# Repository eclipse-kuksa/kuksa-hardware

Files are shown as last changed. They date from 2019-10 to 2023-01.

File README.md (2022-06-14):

# Eclipse KUKSA CANOPi  Hardware 

This repository contains information and manufacturing files for the CANOPi automotive prototyping plattform.

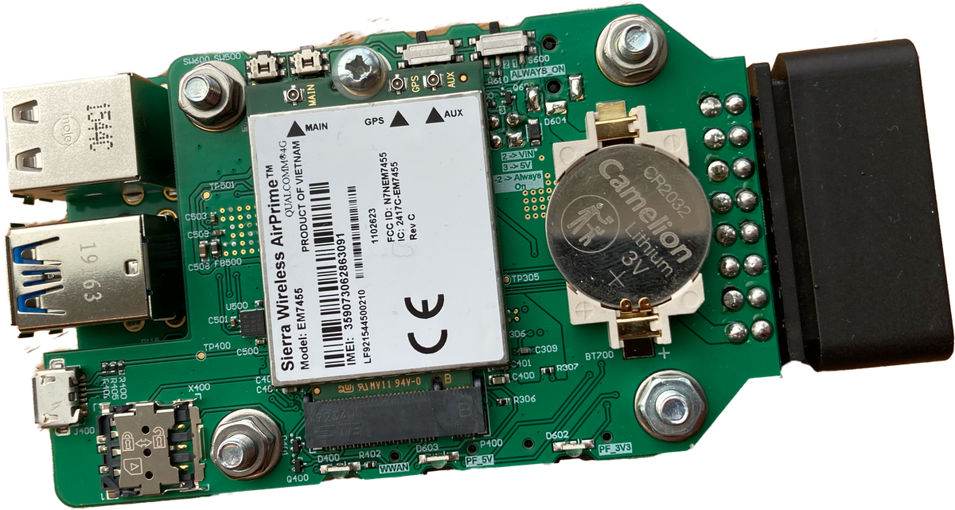
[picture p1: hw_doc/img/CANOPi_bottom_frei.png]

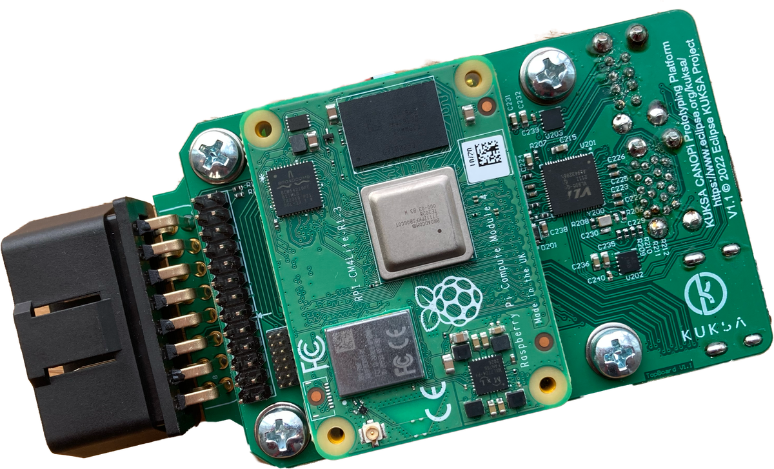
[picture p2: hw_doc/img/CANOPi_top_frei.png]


The Eclipse KUKSA CANOPi is a baseboard for the [Raspberry Compute Module 4 (CM4)](https://www.raspberrypi.com/products/compute-module-4).

With the CANOPi you have all the ingredients for hacking vehicles and prototyping Software Defined Vehicle functions and applications.

 * Compatible with the Raspberry Pi ecosystem thanks to the CM4
 * Up to 8GB of RAM and up to 32GB eMMC or any size micro SD card storage
 * integrated SIM card slot and M2 slot to add cellular connectivity
 * Can be powered via a vehicle's [OBD Port](https://en.wikipedia.org/wiki/On-board_diagnostics#OBD-II) 
 * [STN2120 OBD-II](https://www.obdsol.com/solutions/chips/stn2120/) to access vehicle data on OBD (only CAN supported by hardware)
 * Two [MCP251xFD](https://www.microchip.com/en-us/product/MCP2518FD) based [CAN-FD](https://en.wikipedia.org/wiki/CAN_FD) interfaces allowing interfacing two vehicle classic CAN or CAN FD busses directly.
 * [PCF85036A Realtime clock](https://www.nxp.com/products/peripherals-and-logic/signal-chain/real-time-clocks/rtcs-with-ic-bus/tiny-real-time-clock-calendar-with-alarm-function-and-ic-bus:PCF850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)

## What you can find here
 * Find schematics board renders and BOM lists in [./hw_doc/](./hw_doc/)
 * You can find GERBER files needed to manufacture the PCB in [./manufacturing](./manufacturing) 
 * [Altium Designer](https://www.altium.com/altium-designer) EDA project file nn case you want to modify the schematics can be found in [./EDA](./EDA). 

## How to setup

If you set up a fresh CM4 that has never been used before in CANOPi you need to update the EEPROM first

 * [Updating CM4 EEPROM for CANOPi](./sw_doc/update_eeprom.md)

 In order to make full use of all hardware components, you need to configure your Raspberry OS

  * [Enabling Hardware support in your OS](./sw_doc/configure_raspberryos.md)

If you use a compute module with integrated flash (eMMC), read

 * [How to flash eMMC compute modules](./sw_doc/flash-emmc.md)

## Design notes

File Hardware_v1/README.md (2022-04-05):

# Eclipse Kuksa Hardware V1

:bangbang: | This folder contains documentation and manufacturing data for version 1 of the KUKSA hardware. For documentation regarding the current version [see here](../README.md)
:---: | :---

Eclipse Kuksa Figure
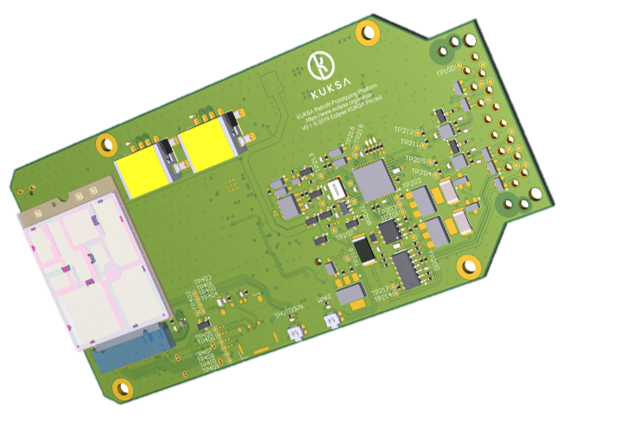
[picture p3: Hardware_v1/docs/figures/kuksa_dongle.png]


This repository contains information about the the Eclipse Kuksa project and available hardware.
It includes hardware schematics and manufacturing files, housing details for 3D printers, as
well as a setup guide. Please use the links below to one of the manuals.

## Eclipse Kuksa Retrofit Dongle

While [Eclipse Kuksa](https://www.eclipse.org/kuksa/) cares about to interconnect
vehicles with external services, typically vehicles already on the road do not
provide any mechanisms to install software afterwards. The Eclipse Kuksa prototyping
platform describes a retrofit solution for already existing vehicles. It can be
directly connected to the in-vehicle OBD II interface. The platform combines a
Raspberry Pi Compute Module, several options to communicate information
(e.g., via cellular or WiFi connectivity) and access to OBD. The most important
information can be accessed in the links below.

## Operational Matters

* [Hardware Schematics](./hardware/Readme.md)
* [3D Housing](./housing/README.md)
* [Setup Guide](./docs/README.md)

## The Project
* [Eclipse Kuksa](https://www.eclipse.org/kuksa/)
* [Licensing](./LICENSE)

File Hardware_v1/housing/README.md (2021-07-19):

# KUKSA.hardware housing

This contains 3d-printable STL files for a housing. 

[housing-top.stl](./housing-top.stl) and [housing-bottom.stl](./housing-bottom.stl) give you the main case (with some handy cutouts from HDMI and the OTG USB port for debugging), while [antenna-bracket-basic.stl](./antenna-bracket-basic.stl) and [antenna-bracket-lock.stl](./antenna-bracket-lock.stl) give support for an LTE antenna and active GPS antenna.

To see how this looks assembled, check the [KUKSA_PiOBD_V0.3.pdf](./KUKSA_PiOBD_V0.3.pdf) file. Please note, the PDF contains a 3D model of the dongle itself inside the housing. This type of content is not supported by many PDF viewers. Therefore, we recommend using the original [Adobe Reader](https://get.adobe.com/reader/) to view it.

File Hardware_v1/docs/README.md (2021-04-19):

# Kuksa Dongle Setup Manual

This documentation provides information about setting up the Kuksa dongle.

## Table of Contents
1. [Hardware Pre-requisites](#hardware-pre-requisites)
2. [OS Installation](#installation-of-os)  
 2.1 [Raspbian OS](#raspbian-os)  
 2.2 [Ubuntu OS](#ubuntu-os)
3. [OBD STN2120 Configuration](#obd-stn2120-configuration)
4. [Configure WiFi Access Point](#configure-wireless-access-point-interface)  
 4.1 [Hostapd Configuration](#hostapd-configuration)  
 4.2 [Dnsmasq Configuration](#dnsmasq-configuration)  
 4.3 [Wireless Interface and Static IP](#wireless-interface-and-static-ip)
5. [Troubleshooting](#troubleshooting)

## Hardware Pre-requisites

##### Mandatory

The Kuksa Dongle is constructed to host and power a Raspberry Pi Compute Module 3 or 3+. Such compute module is required for the dongle and needs to be available.
Check official Raspberry Pi website for further information on the [Raspberry Pi Compute Module 3](https://www.raspberrypi.org/products/compute-module-3/).  
There are actually several versions you can order.
We can recommend to use a **Compute Module Lite** as it allows to mount a SD Card
with an associated operating system. This is much more convenient than flashing
the OS onto the board. In order to install any operating system, a SD card with
sufficient space (e.g., 32GB) is required.

* RaspberryPi Compute Module 3
* SD card (32 GB)

##### Optional

In order to be able to send and receive messages via the OBD interface, a OBD-II emulator like the [FreeMatics OBD-II Emulator Mk2](https://freematics.com/products/freematics-obd-emulator-mk2/) is recommended.

## Installation of OS

This guide provides information to install either the Raspbian OS (32bit system), as well as an Ubuntu Server (headless, 64bit system). If you plan to use the [Kuksa.val](https://github.com/eclipse/kuksa.val) Docker containers, we recommend to install the Ubuntu Server (64bit) system.

### Raspbian OS

Most convenient way to setup an operating system for Raspberry Pi is the Raspbian OS.
We tested the Dongle with [Raspbian LITE OS](https://www.raspberrypi.org/software/operating-systems/) in kernel version 5.10.
Download it from the Raspberry Pi website and install the image on a SD card (e.g., using the [Balena Etcher](https://www.balena.io/etcher/) tool).

When you boot the OS the first time, you need to disable the serial console (otherwise you will face a kernel panic). This is due to the fact, that the port is used by the OBD-II protocol decoder.
You have to mount */boot partition* of the SD card (e.g., Windows or Linux machine), and edit the **cmdline.txt** by deleting the **console=serial0,115200** command. Change it from

```sh
# before the changes
dwc_otg.lpm_enable=0 console=serial0,115200 console=tty1 root=PARTUUID=<PARTION_UUID_VALUE> rootfstype=ext4 elevator=deadline fsck.repair=yes rootwait quiet splash plymouth.ignore-serial-consoles
```
to

```sh
# after the changes
dwc_otg.lpm_enable=0 console=tty1 root=PARTUUID=<PARTION_UUID_VALUE> rootfstype=ext4 elevator=deadline fsck.repair=yes rootwait quiet splash plymouth.ignore-serial-consoles
```
After the changes you can plug the SD card into the dongle, power it up and log into it using the default user:password credentials of Raspian ("*pi:raspberry*").

### Ubuntu OS

The Kuksa Dongle uses a Raspberry Pi Compute Module 3 B+ (w/o internal storage).
This allows us to use a Raspberry Pi compliant operating system on a SD card.
We are using an ARM supported [Ubuntu Server](https://ubuntu.com/download/raspberry-pi/thank-you?version=20.04.2&architecture=server-arm64+raspi) (64bit system - ARM compliant - headless).

In this version of documentation, Ubuntu 20.10 is used -- Problems are faced when using Ubuntu 20.04 LTS.

Download it from the Ubuntu website and install the image on a SD card (e.g., using the [Balena Etcher](https://www.balena.io/etcher/) tool).

When you boot the OS the first time, you need to disable the serial console (otherwise you will face a kernel panic) as well as some labling of network interfaces.

You have to mount */boot partition* of the SD card (e.g., Windows or Linux machine), and edit the **cmdline.txt** by deleting the **console=serial0,115200** command. Change it from

```sh
# before the changes
dwc_otg.lpm_enable=0 console=serial0,115200 console=tty1 root=LABEL=writable rootfstype=ext4 elevator=deadline rootwait fixrtc quiet splash
```
to

```sh
# after the changes
dwc_otg.lpm_enable=0 console=tty1 root=LABEL=writable rootfstype=ext4 elevator=deadline rootwait fixrtc net.ifnames=0
```
After the changes you can plug the SD card into the dongle, power it up and log in with the default Ubuntu credentials (**ubuntu:ubuntu**). Ubuntu will ask you immediately to provide a new password of your choice.

#### Configure Network Interfaces in Ubuntu

In Ubuntu 20.10, **Netplan** is used to configure network interfaces. In order to configure wired and wireless network interfaces, you have to configure the **50-cloud-init.yaml** file, for example:

```sh
ubuntu@ubuntu:~$ sudo nano /etc/netplan/50-cloud-init.yaml
...
...
# This file is generated from information provided by the datasource.  Changes
# to it will not persist across an instance reboot.  To disable cloud-init's
# network configuration capabilities, write a file
# /etc/cloud/cloud.cfg.d/99-disable-network-config.cfg with the following:
# network: {config: disabled}
network:
    renderer: networkd
    ethernets:
        eth0:
            dhcp4: true
            optional: true
            #set-name: eth0
    version: 2
    wifis:
        wlan0:
            optional: true
            access-points:
                "<SSID>":
                    password: "<PASSWD>"
            dhcp4: true
```

Where **<SSID>** is the identification name of your Wifi network and **<PASSWD>** is the password to authenticate the node to your Wifi network. Once the network has been configured, you have to restart the network manager or reboot your system to get the changes effective.

## OBD STN2120 Configuration

The board is designed to use the [STN2120 Chip](https://www.obdsol.com/solutions/chips/stn2120/) for OBD-II connectivity to send and receive messages form a Controller Area Network (CAN). The chip is ELM327 compatible, but bigger, faster and meaner!. You have to configure the baud rate of the CAN transceiver to the serial console in order to receive messages correctly.

Once you have installed any Debian based operating system (e.g., Raspbian OS, or Ubuntu), you have to configure the ELM327 serial bus to read/write to CAN transceiver. On the Dongle, you have to establish a connection to the CAN transceiver (e.g., using the "screen" command line tool - use "sudo apt get install screen" if not installed). Via "dmesg" you can check for the CAN transceiver device (typically */dev/ttyAMA0*).
Once connected, you need to configure the ELM327 baud rate. You can check the entire [STN2120 Chip Manual](https://www.scantool.net/scantool/downloads/98/stn11xx21xx_frpm-c.pdf) for further configuration options.

```sh
# connect to the ELM327 serial bus using 'screen'
kuksa@pi:~$ sudo screen /dev/ttyAMA0 9600
> STSBR 2000000     # configure the baud rate to 2 MBit/s in RAM
> "OK"              # prompts OK
> <CTRL + K>        # exit screen or CTRL + ALT + DEL to reboot the Dongle
# connect again to persist the config changes
kuksa@pi:~$ sudo screen /dev/ttyAMA0 2000000
> STWBR             # persist baud rate in ROM -> there will be NO response
> <CTRL + K>        # exit screen or CTRL + ALT + DEL to reboot the Dongle
```

You are DONE. Your CAN transceiver is configured. In order to test your CAN communication, you can create a Python script to test the CAN communication (e.g., https://python-obd.readthedocs.io/en/latest/). Please check the python-obd manual to check the properties to set to connect to the serial bus and configure the new baud rate.

```python
# pip3 install obd
# python3 python-obdtest.py
import obd

connection = obd.OBD(portstr="/dev/ttyAMA0", baudrate=2000000) # create connection

cmd = obd.commands.SPEED # select an OBD command (sensor)

response = connection.query(cmd) # send the command, and parse the response

print(response.value) # returns unit-bearing values thanks to Pint
print(response.value.to("mph")) # user-friendly unit conversions
```

We suggest to use the FreeMatics OBD-II Emulator Mk2: https://freematics.com/products/freematics-obd-emulator-mk2/  to send CAN messages to the Kuksa Dongle which you should receive on the Python script.

## Configure Wireless Access Point Interface

In order to be able to access in-vehicle data in a real deployment of the Dongle, wireless connectivity is required.
The simplest way to achieve such functionality is to configure a wireless network interface to act as an access point using WiFi.

#### Why do you need a WiFi USB Dongles and which one?

As the Raspberry Pi Compute Module 3 does not provide a WiFi card onboard, you have to order a **mini** WiFi USB dongle (small form factor to fit into the Kuksa Dongle housing). Not all dongles work out of the box with Ubuntu due to missing support of the chip set in the Linux kernel. We tested a couple of Dongles (in 2020/2021) and had good experience with WiFi Dongles equipped with a **Ralink RT5370** chip (e.g., [EDUP Nano Adapter EP at Amazon](https://www.amazon.de/-/en/gp/product/B00BXWU7X4/ref=ppx_yo_dt_b_asin_title_o00_s00?ie=UTF8&psc=1)).

### Pre-requisites

To configure a access point on the Kuksa Dongle, we need three features: (i) tool to switch a Wifi PHY/MAC into access point mode - here using **hostapd**, (ii) a tool to act as a DHCP server and route traffic on this interface accordingly - here using **dnsmasq**, and (iii) configuring a wireless network interface in you network manager (e.g., using netplan or systemd-networkd). In this documentation we are using **systemd-networkd** which is more stable and simple to configure the network interface compared to netplan.

Install the tools via command line:

```sh
ubuntu@ubuntu:~$ sudo apt install hostapd dnsmasq
```

**Attention: When you have set up a wireless interface previously to operate as a client (cf. [Configure Network Interfaces in Ubuntu](#configure-network-interfaces-in-ubuntu)), you have to ensure that you are configuring the right interface to act as a WiFi access point. In case it should be the previously configured *wlan0* interface, you have to delete the lines configured */etc/netplan/50-cloud-init.yaml* file accordingly. If you want to configure an additional one, make sure you are configuring the right interface in the upcoming subsections.**

### Hostapd Configuration

Hostapd allows us to switch a WiFi card or WiFi USB dongle into the access point mode and to configure access point related information such as the SSID or the authentication password. After installing the tool, you have to provide a configuration for your access point. Write the following lines in the configuration file:

```sh
ubuntu@ubuntu:~$ sudo nano /etc/hostapd/hostapd.conf
interface=<INTERFACE>
driver=nl80211
ssid=<YOUR_SSID>
hw_mode=g
channel=7
wmm_enabled=0
macaddr_acl=0
auth_algs=1
ignore_broadcast_ssid=0
wpa=2
wpa_passphrase=<YOUR_PASSWORD>
wpa_key_mgmt=WPA-PSK
wpa_pairwise=TKIP
rsn_pairwise=CCMP
```
where *<INTERFACE>* is the network interface to switch into access point mode (e.g., wlan0), *<YOUR_SSID>* is the name of your wireless network (e.g., KuksaWifi), and *<YOUR_PASSWORD>* is the password used for authentication (make sure that your passphrase is at least 8 characters long).

You can check your configuration file using the following command:

```sh
ubuntu@ubuntu:~$ sudo hostapd -dd /etc/hostapd/hostapd.conf
```

After your configuration has been validated, we have to tell the hostapd systemd service which configuration file to be used (default is none - so change the line starting with *#DAEMON_CONF*) as well as enable the service at boot phase of the system.

```sh
ubuntu@ubuntu:~$ sudo nano /etc/default/hostapd
...
DAEMON_CONF="/etc/hostapd/hostapd.conf"
...
ubuntu@ubuntu:~$ sudo systemctl unmask hostapd
ubuntu@ubuntu:~$ sudo systemctl enable hostapd
ubuntu@ubuntu:~$ sudo systemctl start hostapd
```

When rebooting your system, you see your configured access network in the list of available WiFi networks (e.g., Laptop or SmartPhone). However, your device gets no IP address assigned so far - this is handled by *dnsmasq* (see below).

### Dnsmasq Configuration

Dnsmasq sets up a DHCP server and a router so devices connecting to the Kuksa Dongle can get an IP address assigned to it.

First, we recommend to make a backup of the default configuration file. After that, provide the inputs of your configuration and reload and enable the tool using systemctl.

By providing the inputs, you can un-comment the predefined entries in the file according to your setup. For a simple setup, the following lines are sufficient:

```sh
ubuntu@ubuntu:~$ sudo cp /etc/dnsmasq.conf /etc/dnsmasq.conf.BACKUP   # make a backup of the default conf
ubuntu@ubuntu:~$ sudo nano /etc/dnsmasq.conf
...
# to manage only WLAN0 interface - make sure the name of the interface is correct
interface=wlan0
# to assign addresses between 192.168.4.2 and 192.168.4.20 with netmask 255.255.255.0 and lease time 24 hours
dhcp-range=192.168.4.2,192.168.4.20,255.255.255.0,24h
...
```
On system startup, dnsmasq will not wait for the configured network interface (e.g., wlan0) to initialize and will fail with error "<INTERFACE> not found".

We need to configure the systemd service to launch after the network is ready. So you have to modify dnsmasq.service file by adding the right target under the *[Unit]* section.

```sh
ubuntu@ubuntu:~$ sudo nano /lib/systemd/system/dnsmasq.service
...
[Unit]
...
After=network-online.target
Wants=network-online.target
...
ubuntu@ubuntu:~$ sudo systemctl reload dnsmasq	# reload dnsmasq config
ubuntu@ubuntu:~$ sudo systemctl enable dnsmasq
```

### Wireless Interface and Static IP

Ubuntu uses by default cloud-init for the initial setup. But the configuration is not that simple/intuitive compared to systemd-networkd. So we are using this network management to configure the wireless network interface. A proper documentation of systemd-networkd can be found on the [Systemd-Networkd ArchLinux Website](https://wiki.archlinux.org/index.php/systemd-networkd).

In order to connect to a wireless network with **systemd-networkd**, a wireless adapter configured is required.

```sh
ubuntu@ubuntu:~$ sudo nano /etc/systemd/network/25-wireless.network
[Match]
Name=wlan0					      # the name of your interface you want to configure

[Network]
DHCP=no						        # 'no' as managed by dnsmasq
Address=192.168.4.1/24		# assign static IP address, link to dnsmasq

ubuntu@ubuntu:~$ sudo systemctl reload dnsmasq	# reload dnsmasq config
ubuntu@ubuntu:~$ sudo systemctl enable dnsmasq
```

After the creating the configuration, you have to reload the service and maybe also enable it to be executed after a reboot of the system.

You are done and should be able to connect another device to the Kuksa Dongle.

After rebooting your system, it could be possible that systemd-networkd is waiting for the network to be initialized, resulting in longer bootup time (message something like "a start job is waiting until the network is configured"). Different proposals to overcome the limitation are described on a [StackOverflow Thread](https://askubuntu.com/questions/972215/a-start-job-is-running-for-wait-for-network-to-be-configured-ubuntu-server-17-1).

## Troubleshooting

#### Failed to start OpenBSD Secure Shell Server
If you see, that sshd service can not be started correctly and ubuntu boots with error message: `Failed to start OpenBSD Secure Shell Server`, run the following command to generate missing key will fix the issue:

```sh
kuksa@pi:~$ sudo ssh-keygen -A
```

#### Enable Docker Daemon Autostart
If you want to use the docker images of the [Kuksa.val](https://github.com/eclipse/kuksa.val) and you do not want to start the containers every time, you can enable the Docker daemon to automatically start after installing docker on the Kuksa Dongle.

```sh
kuksa@pi:~$ sudo systemctl enable docker
```

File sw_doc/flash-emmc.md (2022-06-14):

# How to flash eMMC Compute Modules

Compute modules witout eMMC ("Lite" versions), boot from the SD card in the CANOPi socket.

Compute Modules with integrated eMMC flash _can not_ boot from an SD card (this is a CM4 hardware limitation), therefore you need to programm the integrated eMMC flash.

Basically the official documentation applies, which you can find [here](https://www.raspberrypi.com/documentation/computers/compute-module.html#flashing-the-compute-module-emmc), or in [Jeff Gerlings nice tutorial](https://www.jeffgeerling.com/blog/2020/how-flash-raspberry-pi-os-compute-module-4-emmc-usbboot
).

These tutorials assume you are using the official [Compute Module 4 IO Board](https://www.raspberrypi.com/products/compute-module-4-io-board/).
In a nutshell, you need to jumper the `nRPI_BOOT` / `disable eMMC boot` jumper connect your board to our computer where you ran a small piece of software, which basiclly turns you compute module into a (slow...) mass storage device exposing the eMMC flash.

So you are wondering, where to find the `nRPI_BOOT` signal to repeat this trickery directly on a CANOPi? 

Glad you asked:

You just need to put a 1.27mm Jumper over  the marked `nPIREBO` pins.

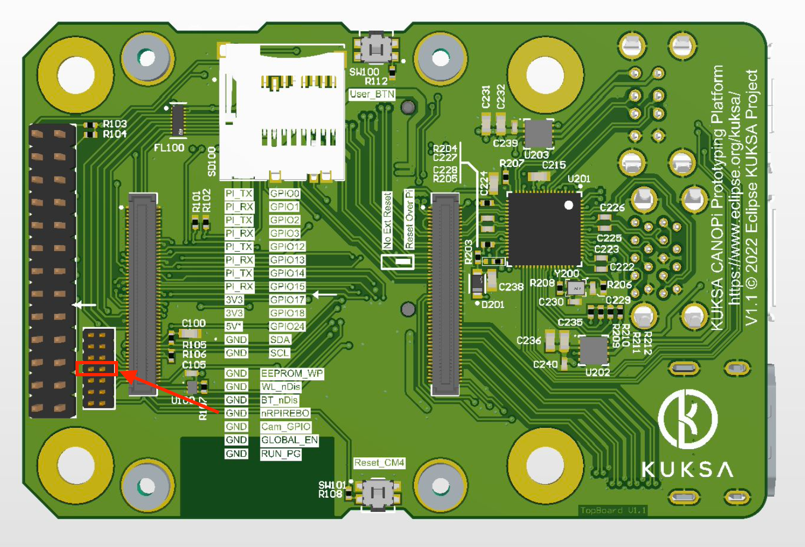
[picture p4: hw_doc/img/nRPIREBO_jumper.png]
nRPIREBO jumper


Do all the flashing as per the linked documentation above, possibly not forgetting to do the [neccessary Raspberry OS modifications](configure_raspberryos.md), remove the jumper and reboot.

Word of warning/friendly advice: Putting the jumper can be tricky and requires a steady hand. Using pincers is recommended. Obviously, only try to set/remove the jumper when the CANOPi is powered off.

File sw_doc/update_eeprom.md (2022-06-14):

# Updating CM4 EEPROM

The CANOPi contains a VIA VL805 4 Port USB controller, just like a "normal" Raspbbery Pi 4. This USB controller needs some firmware loaded up during system initialization, before Linux boots.

As a vanilla CM4 does not contain this USB controller, it will not do that. Therefore we need to update the EEPROM on board the CM4. Normally you only need to do this once for any new CM4, the changes will survice reinstalling or changing the operating system, as long as you do not update the EEPROM again.

The procedure desrcribed here involves a second Raspberry Pi (any will do) with a second SD-card.

## Step-by-step guide
[Prepare two SD-cards](https://www.raspberrypi.com/software/) with the most recent version of Raspberry Pi OS (at least the release of Oct 5th 2021).
One card is designated to be used for the CM4 in the CANOPi OBD dongle. Insert the _first_ card into a Raspberry Pi (any Pi will do - there, you have support for keyboard and mouse) and type

```
sudo nano /boot/config.txt
```

And add the following lines

```
enable_uart=1
dtoverlay=dwc2,dr_mode=host
````

Press Ctrl-X to leave the editor and choose to save your changes.

Then type

```
sudo nano /etc/default/rpi-eeprom-update
```

And change it to include these lines

```
FIRMWARE_RELEASE_STATUS="stable"
CM4_ENABLE_RPI_EEPROM_UPDATE=1
```

Again, press Ctrl-X and choose to save cahnges.

Now, insert this SD card into the CANOPi dongle. That is, the _first_ SD card now moved from the Pi to the CANOPi. Put the CANOPi to the side. We will need it later.

Proceed to the _second_ SD card and insert it into the Raspberry Pi and boot it.

Make sure the Pi has Internet access and type

```
sudo apt install git libusb-1.0-0-dev build-essential
```

Next install usbboot

```
git clone --depth=1 https://github.com/raspberrypi/usbboot
cd usbboot
make
```

Remove the pieeprom.original and replace with the one to flash. Navigate to and remove the original file by typing

```
cd ~/usbboot/recovery
rm -f pieeprom.original.bin
```

Download a recent stable eeprom from https://github.com/raspberrypi/rpi-eeprom/raw/master/firmware/stable/,
for example

```
curl -L -o pieeprom.original.bin https://github.com/raspberrypi/rpi-eeprom/raw/master/firmware/stable/pieeprom-2022-04-26.bin
```

Edit the **boot.conf** file to support the VL805 USB controller and configure proper poweroff behavior for CANOPi. Therefore, type

```
sudo nano ~/usbboot/recovery/boot.conf
```

And modify it to include the following lines

```
WAKE_ON_GPIO=0
POWER_OFF_ON_HALT=1

VL805=1
```

Press Ctrl-X and save.

Now update pieeprom.bin with the configuration in `boot.conf` by typing (still in `~/usbboot/recovery/`)

```
sudo ./update-pieeprom.sh
```

Now  prepare to flash the target by typing

```
cd ~/usbboot
sudo ./rpiboot -d recovery
```

Live the Pi. Now turn you attention back to the CANOPi.
Fit a jumper on `nRPIREBO` and `GND`. You can find the pin header on the top board. see the following picture for reference

nRPIREBO jumper

Fit a CM4. If you have followed this fine manual, the _first_ SD card is still inserted.

Now, connect one USB port from the Raspberry Pi to the microUSB port of the CANOPi dongle. Power on the CANOPi dongle and the flash process should initiate.  A regular blinking pattern of the green LED or, in case a screen is connected, an entirely green screen indicates a finished and successful flash procedure.

Now, power off CANOPi dongle, remove the jumper and power the board back on. The CANOPi dongle should boot normally and, once the CM4 is started, USB devices should be fully supported by the dongle.

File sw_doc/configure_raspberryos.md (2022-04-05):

# Enabling Hardware support in your OS

To be able to make use of all hardware on CANOPi you need to configure your Linux distribution accordingly.

This guide assumes you are using a current (as of 2022) Raspberry Pi OS version based on Debian Bullseye.

The instructions should work on other distributions that also follow the Raspberry OS boot procedure providing a similarly recent kernel.

Before booting the first time the OS on the device, you have to modify the `config.txt` file on the boot partition to extend the device tree. The device tree is the structure that tells the Linux kernel which hardware is available. As the boot partition is a FAT partition you can make these modifications easily even on Windows or OS X after [flashing the operating system](https://www.raspberrypi.com/software/), before booting the first time

## General settings
Make sure you have the following entries in you `config.txt`

```
enable_uart=1
dtoverlay=dwc2,dr_mode=host
```

also edit `cmdline.txt` and **remove** the entry `console=serial0,115200`

## CAN FD controllers
CANOPi has two CAN FD controllers connected via SPI. To enable than uncomment/add the following lines in `config.txt`

```
dtparam=spi=on
dtoverlay=mcp251xfd,spi0-0,interrupt=27,oscillator=20000000
dtoverlay=mcp251xfd,spi0-1,interrupt=22,oscillator=20000000
```

After reboot check, if the `can0` and `can1` interfaces are available, i.e. using

```
ifconfig -a
````

or

```
dmesg | grep spi
```

To learn how to configure the interfaces check [here](https://python-can.readthedocs.io/en/master/interfaces/socketcan.html) or [here](https://www.kernel.org/doc/html/latest/networking/can.html) for more in-depth information

## STN2120 OBD controller

Fit jumpers between GPIO15 and PI_RX and GPIO14 and PI_TX.

You can find the headers on the top board, see the following picture for reference

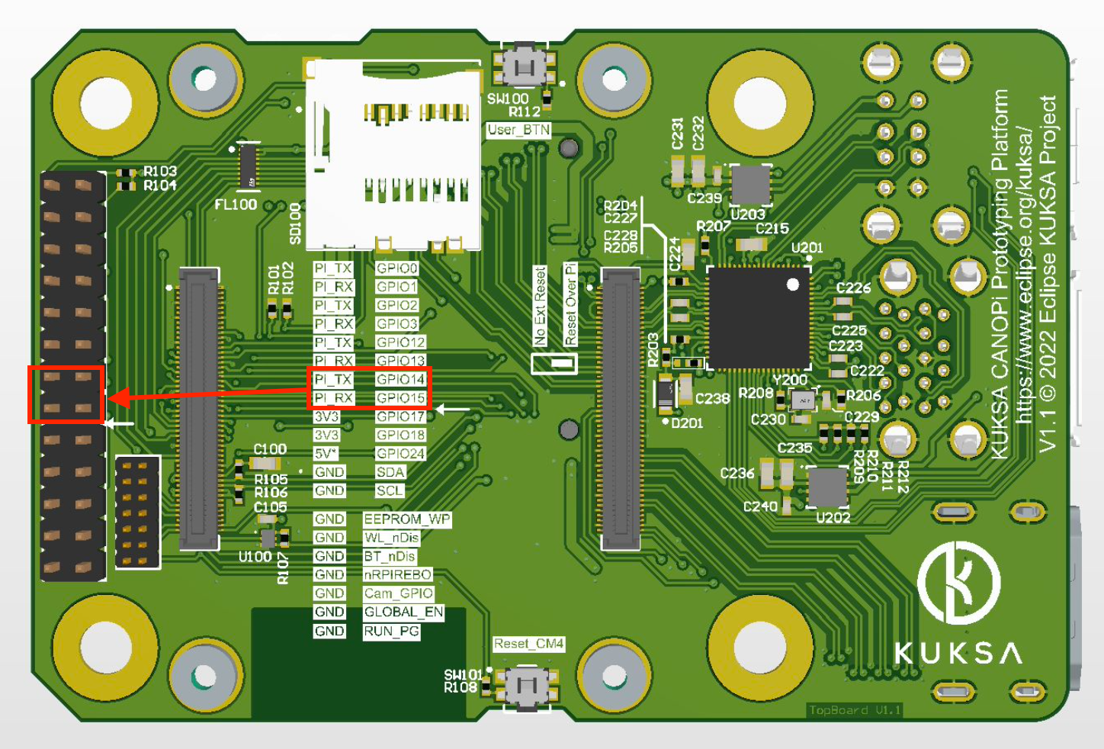
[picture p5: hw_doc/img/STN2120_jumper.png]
STN2120 jumper


Double check you **removed**  `console=serial0,115200` from `cmdline.txt` and boot CANOPi.

In default configuration the OBD chip uses 9600 baud. You can connect using screen like this

```
screen /dev/ttyS0 9600 81N
```

When you enter `STI` the OBD IC should answer with its firmware version.

To enable wakeup trigger send `STSLVG ON`, then you can send the chip to sleep by sending `STSLEEP`.

This sets the chip into sleep mode. The LED STAT turns into burst mode (only emits short bursts of light and stays off most of the time). A push on the WAKE_STN button should wake the chip back up.

For more information on the supported commands check [general information](https://www.obdsol.com/solutions/chips/stn2120/) and the [programming manual](https://www.scantool.net/scantool/downloads/98/stn11xx21xx_frpm-c.pdf).

If you want to use the OBD port, we recommend increasing the default baudrate. See the programming manual for details. You can also (mis)-use the OBD connection as general CAN sniffer, but there are performance limitations. See the [KUKSA.val DBC feeder documentation](https://github.com/eclipse/kuksa.val/tree/master/kuksa_feeders/dbc2val#elmobdlink-support) for details. Generally we recommend using the real CAN ports for CAN access, and use the STN2120 for OBD access only.

## Realtime Clock
CANOPi contains an RTC, which means the board can keep time even when powered of. This is important because most cryptographic protocols break if a system comes back with a wrong time.

To use the RTC uncomment/add the following lines to `config.txt`

```
dtparam=i2c_vc=on
dtoverlay=i2c-rtc,pcf85063a,i2c_csi_dsi,addr=0x51
```

Reboot and type

```
dmesg | grep rtc
```

 to see whether the clock has been detected and

```
sudo hwclock
```

to show the system clock.

## Camera

To enable the camera port you need to download https://datasheets.raspberrypi.com/cmio/dt-blob-cam1.bin and rename it to `dt-blob.bin` and put it into your /boot partition.

If you have already booted the OS you can achieve it by typing

```
sudo wget https://datasheets.raspberrypi.com/cmio/dt-blob-cam1.bin -O /boot/dt-blob.bin
```

Make sure you uncomment/add the following lines to `config.txt`

```
dtoverlay=vc4-kms-v3d
camera_auto_detect=1
```

And then reboot. Check the [Raspberry camera documentation](https://www.raspberrypi.com/documentation/accessories/camera.html) for further information.

## Enable Cellular card
If you fitted a cellular modem to the M2 slot, you need to enable the card first

On the CANOPi type

```
sudo -i
echo "16" > /sys/class/gpio/export
echo "out" > /sys/class/gpio/gpio16/direction
echo "1" >/sys/class/gpio/gpio16/value
```
This creates a handle for GPIO pin 16, declares it as output and sets it to HIGH. GPIO pin 16 carries a signal called "Full Card Power OFF LTE" which, set to HIGH, turns on the LTE module. After a couple of seconds the module has started. Also, a red WWAN LED turns on.

You should be able to see the card on the USB bus by typing

```
lsusb
```

This shoudl work with any Linux supported cellular card. We had success with a [Sierra Wireless EM7455](https://www.sierrawireless.com/iot-solutions/products/em7455/).

## Fan control
The CANOPi dongle offers a dedicated switchable power connection to operate a fan. The connection can be configured to supply either the input voltage (typically 12V) or a 5V voltage at a maximum current of 115mA (default is 5V). 

To change the voltage, move Jumper JP600 (on the back side) from position 1-3 (5V) to position 1-2 (VIN). The combinations are also indicated on the silk screen.

The fan is connected to Pins 1 and 2 on the JP601 header. If unsure about the jumper setting, measure voltage across this pins first, before connecting fan.

Type

```
sudo -i
echo "25" > /sys/class/gpio/export
echo "out" > /sys/class/gpio/gpio25/direction
```

To establish an output port at GPIO pin 25. Internally this pin 25 is connected to operate the switchable power connection.

To switch the fan on

```
echo "1" >/sys/class/gpio/gpio25/value
```

To switch it off

```
echo "0" >/sys/class/gpio/gpio25/value
```

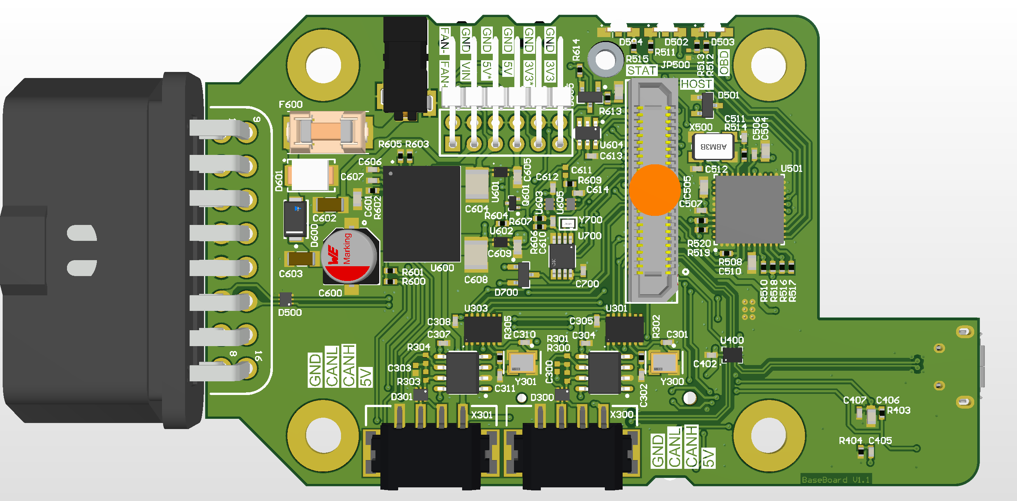
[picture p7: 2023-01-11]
hw_doc/img/CANOPi_Baseboard_TOP(BASIC).png

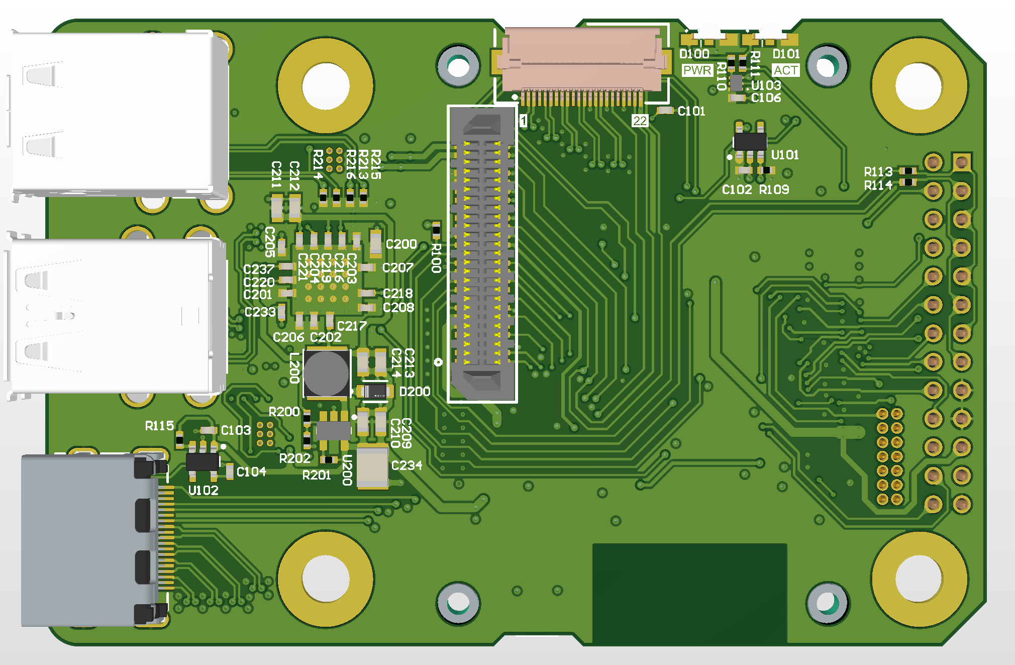
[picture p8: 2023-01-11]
hw_doc/img/CANOPi_Topboard_BOT(BASIC).png

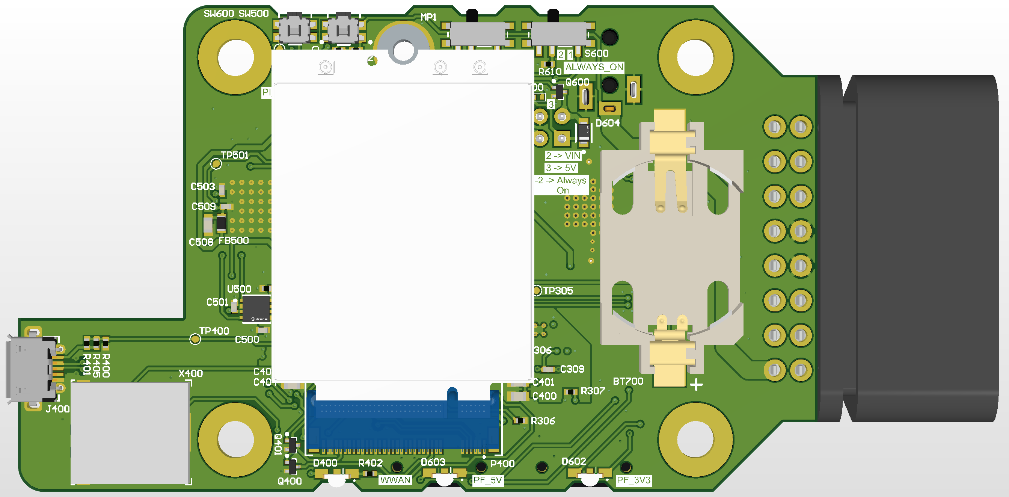
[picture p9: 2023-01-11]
hw_doc/img/CANOPi_Baseboard_BOT(BASIC).png

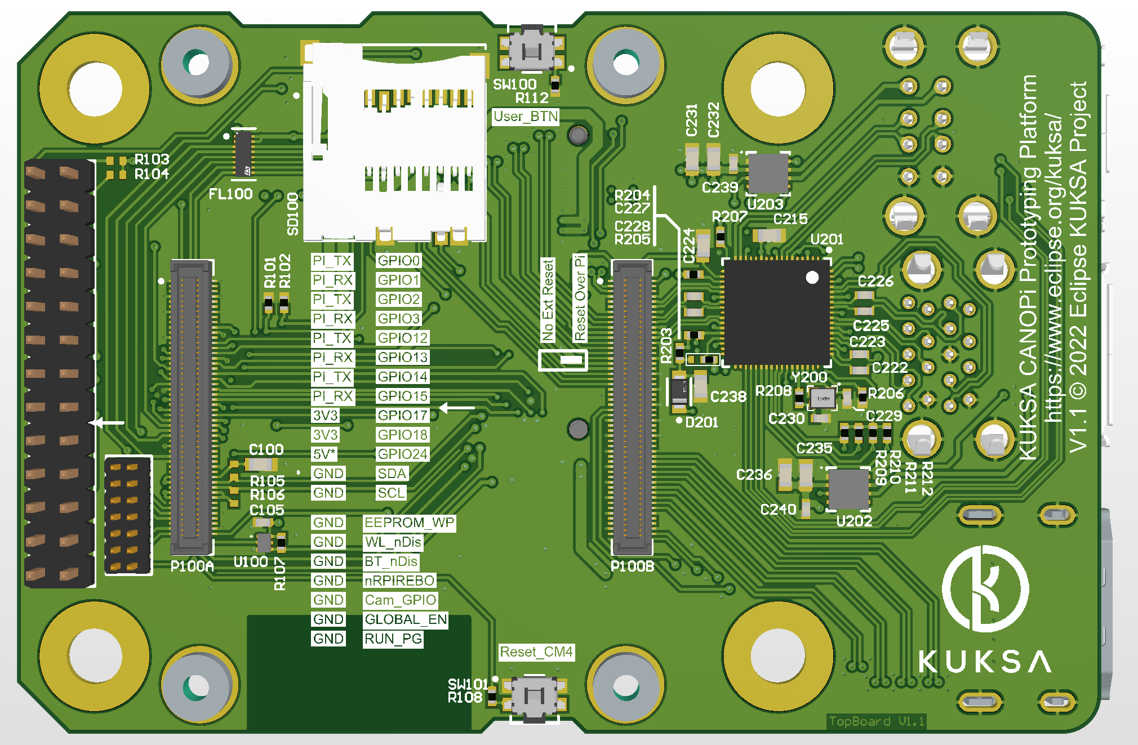
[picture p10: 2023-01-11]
hw_doc/img/CANOPi_Topboard_TOP(BASIC).png

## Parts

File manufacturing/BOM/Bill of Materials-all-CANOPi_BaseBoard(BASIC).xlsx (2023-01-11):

Quantity | Designator | Value | Comment | Description | Footprint | Fitted
1 | BT700 |  | KEYSTONE - 1060 | Batterie Halter (offen) Kreisförmige Scheibe, 20,0mm 1 Zellen SMD (SMT) Tab | KEYSTONE - 1060-Footprint-1 | Fitted
0 | C300, C303, C502, C611 | 100nF | CAP 0402 100n -10% +10% 6.3V X7R | SMD/SMT 0402 6.3V -10% +10% X7R - Multilayer Ceramic Capacitors MLCC | CAP 0402 [1005 Metric] X050 N | Not Fitted
5 | C301, C302, C310, C311, C405 | 27pF | CAP 0402 27p -2% +2% 25V C0G | SMD/SMT 0402 25V -2% +2% C0G - Multilayer Ceramic Capacitors MLCC | CAP 0402 [1005 Metric] X050 N | Fitted
23 | C304, C305, C306, C307, C308, C309, C402, C407, C500, C501, C503, C506, C507, C509, C606, C607, C610, C612, C613, C614, C615, C616, C700 | 100nF | CAP 0402 100n -10% +10% 6.3V X7R | SMD/SMT 0402 6.3V -10% +10% X7R - Multilayer Ceramic Capacitors MLCC | CAP 0402 [1005 Metric] X050 N | Fitted
5 | C400, C403, C510, C605, C609 | 10µF | CAP 0603 10µF -20% +20% 6.3V X5R | SMT 10µF ±20% 6,3 V Keramikkondensatoren X5R | CAP 0603 [1608 Metric] X080 N | Fitted
7 | C401, C404, C406, C504, C505, C508, C617 | 1µF | CAP 0603 1u -10% +10% 10V X7R | SMD/SMT 0603 10V -10% +10% X7R - Multilayer Ceramic Capacitors MLCC | CAP 0603 [1608 Metric] X080 N | Fitted
2 | C511, C512 | 15pF | CAP 0402 15p -2% +2% 25V C0G | SMD/SMT 0402 25V -2% +2% C0G - Multilayer Ceramic Capacitors MLCC | CAP 0402 [1005 Metric] X050 N | Fitted
1 | C600 | 47µF | CAP2625 47u -20% +20% 50V | WCAP-ASLL Aluminium Electrolytic Capacitor (SMD Type): -55°C to 105°, Reflow Soldering, Low Impedance | WCAP-ASLI_6.3x7.7 | Fitted
1 | C601 | 100nF | CAP 0603 100n -10% +10% 50V X7R | SMD/SMT 0603 50V -10% +10% X7R - Multilayer Ceramic Capacitors MLCC | CAP 0603 [1608 Metric] X080 N | Fitted
2 | C602, C603 | 10µF | CAP 1206 10u -10% +10% 50V X5R | Multilayer Ceramic Capacitors MLCC - SMD/SMT 10uF 50Volts 10% | CAP 1206 [3216 Metric] X160 N | Fitted
2 | C604, C608 | 100µF | CAP 1210 100µF +/-20% 16V X5R | 100µF ±20% 16V Ceramic Capacitor X5R 1210 (3225 Metric) | CAP 1210 [3225 Metric] X250 N | Fitted
3 | D300, D301, D500 |  | VISHAY - VBUS052CD-FAH-GS08 | 2-Line BUS-Port ESD-Protection - Flow Through Design | VISHAY - VBUS052CD-FAH | Fitted
3 | D400, D602, D603 |  | WUERTH ELEKTRONIK - 155124RS73200 | LED, RED, Right Angle SMD 3.2*1.0mm WL-SMSW SMT Mono-color Side view Waterclear | WUERTH ELEKTRONIK - WL-SMSW | Fitted
2 | D501, D605 |  | INFINEON - BAT64-04 | Dual Silicon Schottky Diodes in series configuration | INFINEON - BAT64-04 | Fitted
3 | D502, D503, D504 |  | WUERTH ELEKTRONIK - 155124VS73200 | LED, GREEN, Right Angle SMD 3.2*1.0mm WL-SMSW SMT Mono-color Side view Waterclear | WUERTH ELEKTRONIK - WL-SMSW | Fitted
1 | D600 | 134pF | VS-15MQ040NTRPBF | DIODE SCHOTTKY 40V 1.5A SMA | FP-95400-MFG | Fitted
1 | D601 |  | STMICROELECTRONICS - SMBJ24A-TR | TVS DIODE unidirectional 24V DO214AA SMB | DO-214AA (SMB) DIOC5436X26N | Fitted
1 | D604 |  | RBE1VAM20ATR | DIODE SCHOTTKY 20V 1A TUMD2M | FP-TUMD2M-MFG | Fitted
1 | D700 |  | INFINEON - BAT64-05 | Dual Silicon Schottky Diodes | INFINEON - BAT64-04 | Fitted
1 | F600 |  | LITTELFUSE - 154002.DRT. | Sicherung 2A - NANO2 > 154 OMNI-BLOK - Fuse and Holder Combination | LITTELFUSE - 154 OMNI-BLOK | Fitted
1 | FB500 |  | MURATA - BLM18AG121SN1D | 120 Ohms @ 100MHz 1 Power Line Ferrite Bead 0603 (1608 Metric) 800mA 180mOhm | Ferrite Beads 0603 (1608 Metric) | Fitted
1 | J400 |  | 629105150921 | Micro USB 2.0 Type AB Receptacle WR-COM, Horizontal, SMT | 629105150921 | Fitted
1 | J600 |  | 694101308002 | DC Power Jack Connector Low Profile WR-DC, Male, Right Angled, THT, 2 A, 12 V | 694101308002 | Fitted
1 | J601 |  | AMPHENOL - 10129382 | Connector Header Through Hole, Right Angle 12 position 0.100" (2.54mm) | AMPHENOL - 10129382-Footprint-1 | Fitted
1 | J700 |  | SAMTEC - ERF8-025-07.0-L-DV-TR | 50 Poliger Steckverbinder Sockel, äußere Abdeckungskontakte Oberflächenmontage Gold | SAMTEC - ERF-025-05.0-L-DV-TR-Footprint-1 | Fitted
0 | JP500 |  | Solder Jumper 0402 unbestückt | Solder Jumper 0402 unbestückt | Solder Jumper 0402 unbestückt | Not Fitted
1 | JP600 |  | Solder Jumper Triple 0402 with Assembly between 1 and 2 | Solder Jumper Triple 0402 with Assembly between 1 and 2 | Solder Jumper Triple 0402 with Assembly between 1 and 2 | Fitted
1 | MP1 |  | WUERTH ELEKTRONIK - 9774015360 | WA-SMSI SMT Steel Spacer with internal Thread, OD 6mm, M3 x 1.5mm | WUERTH ELEKTRONIK - 9774015360 | Fitted
1 | P400 |  | TE CONNECTIVITY - 2199119-3 | The M.2 (Next Generation Form Factor) product line is a natural transition from the Mini Card and Half Mini Card to a smaller form factor in both size and volume. | M.2 (NGFF) Connectors | Fitted
5 | Q400, Q401, Q600, Q601, Q602 |  | DIODES INCORPORATED - 2N7002T | N-CHANNEL ENHANCEMENT MODE FIELD EFFECT TRANSISTOR | DIODES INCORPORATED - SOT523 | Fitted
0 | R300, R301, R303, R304, R500, R501 | 60.4 | RES 0402 60R4 1% 0W0625 | RC0402 series chip resistor with lead-free terminations made by thick film process | RES 0402 [1005 Metric]_N | Not Fitted
4 | R302, R305, R514, R613 | 100 | RES 0402 100R 1% 63mW | RC0402 series chip resistor with lead-free terminations made by thick film process | RES 0402 [1005 Metric]_N | Fitted
6 | R306, R307, R504, R505, R506, R509 | 10k | RES 0402 10K 1% 0W0625 | RC0402 series chip resistor with lead-free terminations made by thick film process | RES 0402 [1005 Metric]_N | Fitted
3 | R400, R401, R405 | 4.7k | RES 0402 4K7 1% 0W0625 | RC0402 series chip resistor with lead-free terminations made by thick film process | RES 0402 [1005 Metric]_N | Fitted
5 | R402, R508, R511, R513, R515 | 1k | RES 0402 1K 1% 0W0625 | RC0402 series chip resistor with lead-free terminations made by thick film process | RES 0402 [1005 Metric]_N | Fitted
4 | R403, R600, R601, R602 | 33k | RES 0402 33K 1% 0W0625 | RC0402 series chip resistor with lead-free terminations made by thick film process | RES 0402 [1005 Metric]_N | Fitted
1 | R404 | 60.4 | RES 0402 60R4 1% 0W0625 | RC0402 series chip resistor with lead-free terminations made by thick film process | RES 0402 [1005 Metric]_N | Fitted
5 | R502, R606, R607, R611, R612 | 330k | RES 0402 330K 1% 0W0625 | RC0402 series chip resistor with lead-free terminations made by thick film process | RES 0402 [1005 Metric]_N | Fitted
1 | R503 | 62k | RES 0402 62K 1% 0W0625 | RC0402 series chip resistor with lead-free terminations made by thick film process | RES 0402 [1005 Metric]_N | Fitted
13 | R507, R510, R512, R516, R517, R518, R519, R520, R604, R608, R609, R610, R614 | 100k | RES 0402 100K 1% 0W0625 | RC0402 series chip resistor with lead-free terminations made by thick film process | RES 0402 [1005 Metric]_N | Fitted
1 | R603 | 45,3k | RES 0402 45K3 1% 0W0625 | RC0402 series chip resistor with lead-free terminations made by thick film process | RES 0402 [1005 Metric]_N | Fitted
1 | R605 | 78.7k | RES 0402 78K7 1% 0W0625 | RC0402 series chip resistor with lead-free terminations made by thick film process | RES 0402 [1005 Metric]_N | Fitted
0 | R700, R701 | 4.7k | RES 0402 4K7 1% 0W0625 | RC0402 series chip resistor with lead-free terminations made by thick film process | RES 0402 [1005 Metric]_N | Not Fitted
2 | S600, S601 |  | C & K - PCM12SMTR | C & K Schiebeschalter PCM12SMTR 1-polig Ein-Ein, 0,3 A @ 6 V dc - Slide Switches 0.3A SPDT ON-ON | PCM12SMTR | Fitted
2 | SW500, SW600 |  | EVQ-P7J01P | SWITCH TACTILE SPST-NO 0.05A 12V | FP-EVQ-P7J01P-MFG | Fitted
2 | U300, U302 |  | MICROCHIP - MCP2542FD/4FD | CAN FD Transceiver with Wake-up Pattern (WUP) Option | SOIC127P600X175-8N | Fitted
2 | U301, U303 |  | MICROCHIP - MCP2518FD | CAN FD Controller with SPI Interface | SON65P300X90_HS-15N | Fitted
1 | U400 |  | ON SEMICONDUCTOR - FSUSB43L10X | Low-Power, Two-Port, High-Speed, USB2.0 (480Mbps) Switch | ON SEMICONDUCTOR - FSUSB43L10X | Fitted
1 | U500 |  | MCP2562-E/MF | IC TRANSCEIVER HALF 1/1 8DFN | FP-C04-062-MFG | Fitted
1 | U501 |  | OBD SOLUTIONS - STN2120 | The STN2120 and STN2100 are OBD to UART interpreter ICs designed to provide bi-directional, halfduplex communication with the vehicle¿s On-Board Diagnostic system (OBD-II). | QFN65P800X800X100_HS-45N | Fitted
1 | U600 |  | ANALOG DEVICES - LTM8024EY#PBF | 40VIN, Dual 3.5A or Single 7A Silent Switcher ¿Module Regulator | ANALOG DEVICES - LTM8024 | Fitted
2 | U601, U602 |  | VISHAY - SIP32408 | 1.1 V to 5.5 V, Slew Rate Controlled Load Switch | DFN130P160X60-4N | Fitted
3 | U603, U605, U606 |  | SN74LVC1G07DRYR | Single Buffer/Driver With Open-Drain Output, DRY0006A, LARGE T&R | DRY0006A_V | Fitted
1 | U604 |  | SN74LVC1G27DBVR | Single 3-Input Positive-NOR Gate, DBV0006A, LARGE T&R | DBV0006A_N | Fitted
1 | U700 |  | PCF85063ATT/AJ | IC RTC CLK/CALENDAR I2C 8TSSOP | FP-SOT505-1-MFG | Fitted
2 | X300, X301 |  | PHOENIX CONTACT - PTSM 0,5/ 4-HH-2,5-SMD R32 | Leiterplatten-Grundleiste - PTSM 0,5/ 4-HH-2,5-SMD R32 | PHOENIX CONTACT - PTSM 0,5_ 4-HH-2,5-SMD R32-Footprint-1 | Fitted
1 | X400 |  | JST - SCZW-7SA-1K(HF) | SIM-Kartenleser aufklappbar und sperrfähig | JST SCZW-7SA-1K(HF) | Fitted
1 | X500 |  | ABM3B-16.000MHZ-B2-T | Ceramic SMD Crystal, 16 MHz, +/- 20 ppm, 50 Ohm, -20 to 70 degC, 4-Pin SMD, RoHS, Tape and Reel | ABRA-ABM3B-4_V | Fitted
1 | X501 |  | COMTECH ELECTRONIC - OBD-2 Stiftblock | OBD-2 Stiftblock männlich PCB TH PKW Typ A | COMTECH ELECTRONIC - OBD-2 Stiftblock-Footprint-1 | Fitted
2 | Y300, Y301 |  | ECS-200-18-33Q-DS | CRYSTAL 20.0000MHZ 18PF SMD | FP-ECX-33Q-MFG | Fitted
1 | Y700 |  | ABRACON - ABS05-32.768KHZ-9-T | Crystals 32.768KHz 9.0pF 20ppm -40C +85C | ABRACON - ABS05-32.768KHZ-9-T | Fitted

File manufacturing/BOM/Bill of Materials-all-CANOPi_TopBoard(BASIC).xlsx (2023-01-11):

Quantity | Designator | Value | Comment | Description | Footprint | Fitted
4 | C100, C232, C236, C238 | 1µF | CAP 0603 1u -10% +10% 10V X7R | SMD/SMT 0603 10V -10% +10% X7R - Multilayer Ceramic Capacitors MLCC | CAP 0603 [1608 Metric] X080 N | Fitted
30 | C101, C102, C103, C104, C105, C106, C201, C202, C203, C204, C205, C206, C207, C208, C216, C217, C218, C219, C220, C221, C222, C223, C225, C226, C227, C228, C233, C237, C239, C240 | 100nF | CAP 0402 100n -10% +10% 6.3V X7R | SMD/SMT 0402 6.3V -10% +10% X7R - Multilayer Ceramic Capacitors MLCC | CAP 0402 [1005 Metric] X050 N | Fitted
11 | C200, C209, C210, C211, C212, C213, C214, C215, C224, C231, C235 | 10µF | CAP 0603 10µF -20% +20% 6.3V X5R | SMT 10µF ±20% 6,3 V Keramikkondensatoren X5R | CAP 0603 [1608 Metric] X080 N | Fitted
2 | C229, C230 | 15pF | CAP 0402 15p -2% +2% 25V C0G | SMD/SMT 0402 25V -2% +2% C0G - Multilayer Ceramic Capacitors MLCC | CAP 0402 [1005 Metric] X050 N | Fitted
1 | C234 | 100µF | CAP 1210 100µF +/-20% 16V X5R | 100µF ±20% 16V Ceramic Capacitor X5R 1210 (3225 Metric) | CAP 1210 [3225 Metric] X250 N | Fitted
1 | D100 |  | WUERTH ELEKTRONIK - 155124RS73200 | LED, RED, Right Angle SMD 3.2*1.0mm WL-SMSW SMT Mono-color Side view Waterclear | WUERTH ELEKTRONIK - WL-SMSW | Fitted
1 | D101 |  | WUERTH ELEKTRONIK - 155124VS73200 | LED, GREEN, Right Angle SMD 3.2*1.0mm WL-SMSW SMT Mono-color Side view Waterclear | WUERTH ELEKTRONIK - WL-SMSW | Fitted
2 | D200, D201 |  | RBE1VAM20ATR | DIODE SCHOTTKY 20V 1A TUMD2M | FP-TUMD2M-MFG | Fitted
1 | FL100 |  | EMIF06-MSD02N16 | FILTER RC(PI) 45 OHM/20PF SMD | FP-EMIF06-MSD02N16-MFG | Fitted
1 | J100 |  | 685119134923 | HDMI Type A Receptacle WR-HDMI, Horizontal, SMT | 685119134923 | Fitted
1 | J101 |  | HIROSE - FH12-22S-0.5SH55 | FFC/FPC Steckverbinder, 22 Positionen, unten 0,020" (0,50mm) Oberflächenmontage, rechtwinklig | HIROSE - FH12-22S-0.5SH55-Footprint-1 | Fitted
1 | J200 |  | MOLEX - 484060003 | Universal Serial Bus (USB 3.0) I/O Receptacle, Dual Port Stacked, Right-Angle, TypeA, High-Temperature Blue Nylon, 0.38¿m Gold (Au) Plating, Contact Height 4.13mm | MOLEX - 484060003 | Fitted
1 | J201 |  | MOLEX - 672984090 | Universal Serial Bus (USB) Shielded I/O Receptacle, Right-Angle, Dual Stacked, Type A, Gold (Au) Flash, White Housing, with 4 Beveled Metal Pins, Lead-Free | MOLEX - 672984090 | Fitted
1 | J202 |  | SAMTEC - ERM8-025-02.0-L-DV-TR | 50 Poliger Steckverbinder Steckleiste, Mittenstreifenkontakte Oberflächenmontage Gold | SAMTEC - ERM8-025-02.0-S-DV-TR-Footprint-1 | Fitted
1 | JP200 |  | Solder Jumper Triple 0402 with Assembly between 1 and 2 | Solder Jumper Triple 0402 with Assembly between 1 and 2 | Solder Jumper Triple 0402 with Assembly between 1 and 2 | Fitted
1 | L200 | 3,3µH | VISHAY - IFSC1515AHER3R3M01 | Low Profile, High Current Inductor | IFSC-1515AH | Fitted
4 | MP1, MP2, MP3, MP4 |  | WUERTH ELEKTRONIK - 9774030151 | WA-SMSI SMT Steel Spacer with internal Thread, OD 5.1mm, M2.5 x 3mm | WUERTH ELEKTRONIK - 9774030151 | Fitted
2 | P100A, P100B |  | RASPBERRY-PI - Compute Modul 4 | Connector Pin 1-100, Parameters from HIROSE - DF40HC(3.0)-100DS-0.4V, Connector Pin 101-200, Parameters from HIROSE - DF40HC(3.0)-100DS-0.4V | HIROSE - DF40HC(3.0)-100DS-0.4V | Fitted
1 | P101 |  | WUERTH ELEKTRONIK - 61302621121 | 26 pin 2.54MM DUAL PIN HEADER | WUERTH ELEKTRONIK - 61302621121 | Fitted
1 | P102 |  | 62201421121 | THT Vertical Pin Header WR-PHD, Pitch 1.27 mm, Dual Row, 14 pins | 62201421121 | Fitted
13 | R100, R101, R102, R107, R201, R209, R210, R211, R212, R213, R214, R215, R216 | 100k | RES 0402 100K 1% 0W0625 | RC0402 series chip resistor with lead-free terminations made by thick film process | RES 0402 [1005 Metric]_N | Fitted
0 | R103, R104, R105, R106 | 4.7k | RES 0402 4K7 1% 0W0625 | RC0402 series chip resistor with lead-free terminations made by thick film process | RES 0402 [1005 Metric]_N | Not Fitted
1 | R108 | 220 | RES 0402 220R 1% 0W0625 | RC0402 series chip resistor with lead-free terminations made by thick film process | RES 0402 [1005 Metric]_N | Fitted
7 | R109, R112, R200, R203, R204, R205, R207 | 10k | RES 0402 10K 1% 0W0625 | RC0402 series chip resistor with lead-free terminations made by thick film process | RES 0402 [1005 Metric]_N | Fitted
5 | R110, R111, R113, R114, R115 | 1k | RES 0402 1K 1% 0W0625 | RC0402 series chip resistor with lead-free terminations made by thick film process | RES 0402 [1005 Metric]_N | Fitted
1 | R202 | 13,3k | RES 0402 13K3 1% 0W0625 | RC0402 series chip resistor with lead-free terminations made by thick film process | RES 0402 [1005 Metric]_N | Fitted
1 | R206 | 6,04k | RES 0402 6K04 1% 0W0625 | RC0402 series chip resistor with lead-free terminations made by thick film process | RES 0402 [1005 Metric]_N | Fitted
1 | R208 | 100 | RES 0402 100R 1% 63mW | RC0402 series chip resistor with lead-free terminations made by thick film process | RES 0402 [1005 Metric]_N | Fitted
1 | SD100 |  | 473521001 | MicroSD(TM), Pitch 1.1 mm, 8 Position, Height 1.88 mm, -20 to 85 degC, RoHS, Tape and Reel | MOLX-473521001_V | Fitted
2 | SW100, SW101 |  | EVQ-P7J01P | SWITCH TACTILE SPST-NO 0.05A 12V | FP-EVQ-P7J01P-MFG | Fitted
2 | U100, U103 |  | SN74LVC1G07DRYR | Single Buffer/Driver With Open-Drain Output, DRY0006A, LARGE T&R | DRY0006A_V | Fitted
2 | U101, U102 |  | ON SEMICONDUCTOR - FPF2109 | The FPF2108-FPF2110 is a series of load switches whichprovides full protection to systems and loads which mayencounter large current conditions. | ON SEMICONDUCTOR - SOT-23, 5 Lead CASE 527AH-01 | Fitted
1 | U200 |  | LM2831XMF | High Frequency 1.5A Load - Step-Down DC-DC Regulator, 5-pin SOT-23 | MF05A_N | Fitted
1 | U201 |  | VIA LABS - VL805 | VL805 4-Port USB 3.0 Host Controller | QFN40P800X800X90_HS-69N | Fitted
2 | U202, U203 |  | DIODES INCORPORATED - AP2182A | Power Switch/Driver 1:2 P-Channel 1.5A U-DFN3030-8 (Type E) | SON65P300X60_HS-9N | Fitted
1 | Y200 |  | ABRACON - ABM11-25.000MHZ-B7G-T | 25.000MHz ±15ppm Crystal 10pF 100 Ohm -20°C +70°C Surface Mount 4-SMD, No Lead (DFN, LCC) | ABM11 | Fitted

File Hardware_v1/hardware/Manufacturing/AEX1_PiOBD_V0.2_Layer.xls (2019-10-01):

Quantity | Designator | Value | Comment | Case | Description | Mounting Type | Fitted | Layer
1 | C200 | 150pF | CAP 0402 150p -5% +5% 25V C0G | 0402 [1005] | SMD/SMT 0402 25V -5% +5% C0G - Multilayer Ceramic Capacitors MLCC | SMT | Fitted | Bottom
1 | C201 | 4,7µF | CAP 0603 4u7 -20% +20% 25V X5R | 0603 [1608] | SMD/SMT 0603 25V -20% +20% X5R - Multilayer Ceramic Capacitors MLCC | SMT | Fitted | Bottom
5 | C202, C204, C207, C210, C213 | 1µF | CAP 0402 1u -10% +10% 10V X6S | 0402 [1005] | SMD/SMT 0402 10V -10% +10% X6S - Mulitlayer Ceramic Capacitors MLCC | SMT | Fitted | Bottom
6 | C203, C208, C216, C217, C506, C514 | 100nF | CAP 0402 100n -10% +10% 35V X5R | 0402 [1005] | SMD/SMT 0402 35V -10% +10% X5R - Multilayer Ceramic Capacitors MLCC | SMT | Fitted | Bottom
4 | C205, C206, C211, C212 | 560pF | CAP 0402 560p -5% +5% 25V C0G | 0402 [1005] | SMD/SMT 0402 25V -5% +5% C0G - Multilayer Ceramic Capacitors MLCC | SMT | Fitted | Bottom
1 | C209 | 10µF | CAP 0603 10µF -10% + 10% 16V X5R | 0603 [1608] | Cap Ceramic 10uF 16V X5R 10% Pad SMD 0603 85 T/R | SMT | Fitted | Bottom
2 | C214, C215 | 30pF | CAP 0402 30p -2% +2% 25V C0G | 0402 [1005] | SMD/SMT 0402 25V -2% +2% C0G - Multilayer Ceramic Capacitors MLCC | SMT | Fitted | Bottom
1 | D100 |  | MMBZ27VCLT1 |  | 40 W Peak Power Zener Transient Voltage Suppressor, Dual Common Cathode Zeners for ESD Protection, 3-Pin SOT-23, Tape and Reel |  | Fitted | Bottom
2 | D101, D102 |  | MMBZ27VALT1 |  | 40 W Peak Power Zener Transient Voltage Suppressor, Dual Common Anode Zeners for ESD Protection, 3-Pin SOT-23, Tape and Reel |  | Fitted | Bottom
2 | D103, D104 |  | PESD1CAN |  | CAN Bus ESD Protection Diode, 200 W, 24 V, -65 to 150 degC, 3-Pin SOT23, RoHS, Tape and Reel |  | Fitted | Bottom
5 | D200, D201, D202, D203, D207 |  | BAS16W |  | Silicon Switching Diode, SOT323, Reel, Green |  | Fitted | Bottom
1 | D400 |  | ROHM - SML-P11MT(R) | 402 | Standard LEDs - SMD Yellowish Green 569nm 2.1mcd 50mW Pd 1.9V Vf | SMT | Fitted | Bottom
3 | FD2, FD3, FD4 |  | Fiducial Marker 1.0mm | 1.0mm | Passermarke / Fiducial Marker / Kammera-Marke 1.0mm Durchmesser , 500µm Lackfreistellung |  | Fitted | Bottom
1 | J300 |  | 62101621021 |  | SMT Vertical Pin Header WR-PHD, Pitch 1.27 mm, Dual Row, 16 pins |  | Fitted | Bottom
2 | J501, J502 |  | 629104190121 |  | USB 2.0 Type A Receptacle WR-COM, Horizontal, SMT, Short Type with Pads and Pegs |  | Fitted | Bottom
0 | JP200, JP201 |  | Solder Jumper 0402 unbestückt | - | Solder Jumper 0402 unbestückt | - | Not Fitted | Bottom
1 | L503 |  | DLP11SN900HL2L |  | Chip Common Mode Choke Coil, 1.5 Ohm, 150 mA, -40 to 85 degC, 4-Pin SMD (1210), RoHS, Tape and Reel |  | Fitted | Bottom
1 | MP1 |  | M2.5, height 1.5mm |  | SMT Steel Spacer with internal Thread M2.5 WA-SMSI, height 1.5mm |  | Fitted | Bottom
1 | P100 |  | COMTECH ELECTRONIC CO., LTD ,CR-PG032 |  | OBD-2 Stiftblock rechtwinklig PCB Montagewinkel | SMT | Fitted | Bottom
1 | P400 |  | TE connectivity M.2 (NGFF) Connectors |  | The M.2 (Next Generation Form Factor) product line is a natural transition from the Mini Card and Half Mini Card to a smaller form factor in both size and volume. | SMT | Fitted | Bottom
6 | Q200, Q201, Q205, Q206, Q209, Q214 |  | IRLML9301TRPBF |  | HEXFET(R) Power MOSFET, 3.6 A, 30 V, -55 to 150 degC, 3-Pin SOT-23, RoHS, Tape and Reel | SurfaceMount | Fitted | Bottom
7 | Q202, Q207, Q208, Q210, Q211, Q212, Q213 |  | ON SEMICONDUCTOR - BSS138 | SOT23-3 | MOSFET N-CH 50V 220MA SOT-23 | SMT | Fitted | Bottom
2 | Q203, Q204 |  | DIODES INCORPORATED - MMBT2222A-7-F | SOT23 | NPN small signal transistor, 40V, 600mA, SOT23 | SMT | Fitted | Bottom
0 | Q400 |  | ON SEMICONDUCTOR - BSS138 | SOT23-3 | MOSFET N-CH 50V 220MA SOT-23 | SMT | Not Fitted | Bottom
8 | R200, R211, R212, R220, R239, R240, R241, R400 | 1k | RES 0402 1K 1% 62.5mW | 0402 [1005] | RC0402 series chip resistor with lead-free terminations made by thick film process | SMT | Fitted | Bottom
1 | R201 | 1,5k | RES 0402 1K5 1% 62.5mW | 0402 [1005] | RC0402 series chip resistor with lead-free terminations made by thick film process | SMT | Fitted | Bottom
1 | R202 | 6.49k | RES 0805 6K49 1% 125mW | 0805 [2012] | RC0805 series chip resistor with lead-free terminations made by thick film process | SMT | Fitted | Bottom
1 | R203 | 130 | RES 2512 130R 1% 2W | 2512 [6432] | Thick film chip resistor 2512, 2W | SMD | Fitted | Bottom
19 | R204, R205, R206, R209, R210, R213, R214, R227, R228, R231, R234, R235, R236, R237, R244, R245, R246, R249, R250 | 10k | RES 0402 10K 1% 62.5mW | 0402 [1005] | RC0402 series chip resistor with lead-free terminations made by thick film process | SMT | Fitted | Bottom
2 | R207, R208 | 510.00 Ohm | 510R 5% 1210(3225) |  | 510R 0.5W 5% 1210 (3225 Metric) SMD |  | Fitted | Bottom
9 | R215, R216, R217, R221, R222, R223, R224, R229, R238 | 100k | RES 0402 100K 1% 62.5mW | 0402 [1005] | RC0402 series chip resistor with lead-free terminations made by thick film process | SMT | Fitted | Bottom
4 | R218, R219, R232, R233 | 100 | RES 0402 100R 1% 62.5mW | 0402 [1005] | RC0402 series chip resistor with lead-free terminations made by thick film process | SMT | Fitted | Bottom
1 | R225 | 240 | RES 0402 240R 1% 62.5mW | 0402 [1005] | RC0402 series chip resistor with lead-free terminations made by thick film process | SMT | Fitted | Bottom
1 | R226 | 866 | RES 0402 866R 1% 62.5mW | 0402 [1005] | RC0402 series chip resistor with lead-free terminations made by thick film process | SMT | Fitted | Bottom
1 | R230 | 374 | RES 0402 374R 1% 62.5mW | 0402 [1005] | RC0402 series chip resistor with lead-free terminations made by thick film process | SMT | Fitted | Bottom
1 | R242 | 10 | RES 0402 10R 1% 62.5mW | 0402 [1005] | RC0402 series chip resistor with lead-free terminations made by thick film process | SMT | Fitted | Bottom
1 | R243 | 2,7k | RES 0402 2K7 1% 62.5mW | 0402 [1005] | RC0402 series chip resistor with lead-free terminations made by thick film process | SMT | Fitted | Bottom
1 | R247 | 330k | RES 0402 330K 1% 62.5mW | 0402 [1005] | RC0402 series chip resistor with lead-free terminations made by thick film process | SMT | Fitted | Bottom
1 | R248 | 62k | RES 0402 62K 1% 62.5mW | 0402 [1005] | RC0402 series chip resistor with lead-free terminations made by thick film process | SMT | Fitted | Bottom
2 | S200, S300 |  | PANASONIC - EVQ-P7M01P | EVQP7M | Tactile Switch SPST-NO Side Actuated Surface Mount, Right Angle | SMT | Fitted | Bottom
1 | U200 |  | LM339DTBR2G |  | Single Supply Quad Comparators, 0 to 70 degC, 14-Pin TSSOP, Pb-Free, Tape and Reel |  | Fitted | Bottom
1 | U201 |  | MELEXIS - TH8056KDC-AAA-008-RE | SOIC-8 | CAN-IC-Schnittstelle Single Wire CAN Transceiver (GMW3089 V2.x) in SOIC8 | SMT | Fitted | Bottom
1 | U202 |  | SN74LVC1G32DBVR |  | Single 2-Input Positive-OR Gate, DBV0005A, LARGE T&R |  | Fitted | Bottom
1 | U203 |  | OBD SOLUTIONS - STN2120 | QFN-44 | The STN2120 and STN2100 are OBD to UART interpreter ICs designed to provide bi-directional, halfduplex communication with the vehicle¿s On-Board Diagnostic system (OBD-II). | SMT | Fitted | Bottom
2 | U204, U206 |  | MICROCHIP - MCP2562-E/MF | SON-8 | High-speed CAN Transceiver with Standby Mode and VIO Pin | SMT | Fitted | Bottom
1 | U205 |  | LM317LD13TR |  | Low Current 1.2 to 37V Adjustable Voltage Regulator, 8-Pin SO, Tape and Reel |  | Fitted | Bottom
1 | X200 |  | ABM3B-16.000MHZ-B2-T |  | Ceramic SMD Crystal, 16 MHz, +/- 20 ppm, 50 Ohm, -20 to 70 degC, 4-Pin SMD, RoHS, Tape and Reel |  | Fitted | Bottom
1 | X400 |  | JST SCZW-7SA-1K(HF) | SIM-Kartenhalter | SIM-Kartenleser aufklappbar und sperrfähig | SMT | Fitted | Bottom
5 | C300, C401, C512, C513, C519 | 4,7µF | CAP 0603 4u7 -20% +20% 25V X5R | 0603 [1608] | SMD/SMT 0603 25V -20% +20% X5R - Multilayer Ceramic Capacitors MLCC | SMT | Fitted | Top
15 | C301, C302, C402, C502, C504, C508, C510, C511, C515, C516, C517, C518, C607, C608, C614 | 100nF | CAP 0402 100n -10% +10% 35V X5R | 0402 [1005] | SMD/SMT 0402 35V -10% +10% X5R - Multilayer Ceramic Capacitors MLCC | SMT | Fitted | Top
1 | C400 | 47pF | CAP 0402 47p -5% +5% 25V C0G | 0402 [1005] | SMD/SMT 0402 25V -5% +5% C0G - Multilayer Ceramic Capacitors MLCC | SMT | Fitted | Top
5 | C501, C503, C509, C603, C610 | 150µF | CAP2625 150u -20% +20% 10V | Radial SMD | WCAP-ASLL Aluminium Electrolytic Capacitor (SMD Type): -55°C to 105°, Reflow Soldering, Low Impedance | SMT | Fitted | Top
2 | C505, C507 | 30pF | CAP 0402 30p -2% +2% 25V C0G | 0402 [1005] | SMD/SMT 0402 25V -2% +2% C0G - Multilayer Ceramic Capacitors MLCC | SMT | Fitted | Top
0 | C520 | 100nF | CAP 0402 100n -10% +10% 35V X5R | 0402 [1005] | SMD/SMT 0402 35V -10% +10% X5R - Multilayer Ceramic Capacitors MLCC | SMT | Not Fitted | Top
1 | C600 | 10nF | CAP 0603 10n -10% +10% 100V X7R | 0603 [1608] | SMT Multilayer Ceramic Chip Capacitor for Non-Magnetic Applications (IR Reflow Soldering) | SMT | Fitted | Top
1 | C601 | 10uF | CAP 10uF 25V 1210(3225) |  | CAP 10uF 25V -20% to +80% 1210 (3225 Metric) Thickness 1.9mm SMD |  | Fitted | Top
2 | C602, C609 | 10µF | CAP 0603 10µF -10% + 10% 16V X5R | 0603 [1608] | Cap Ceramic 10uF 16V X5R 10% Pad SMD 0603 85 T/R | SMT | Fitted | Top
4 | C604, C611, C612, C613 | 1µF | CAP 0402 1u -10% +10% 10V X6S | 0402 [1005] | SMD/SMT 0402 10V -10% +10% X6S - Mulitlayer Ceramic Capacitors MLCC | SMT | Fitted | Top
9 | D204, D205, D206, D300, D301, D302, D501, D503, D505 |  | ROHM - SML-P11MT(R) | 402 | Standard LEDs - SMD Yellowish Green 569nm 2.1mcd 50mW Pd 1.9V Vf | SMT | Fitted | Top
3 | D500, D502, D504 |  | BGX50A |  | Silicon Switching Diode Array, SOT143-4-1, Reel, Green |  | Fitted | Top
3 | D506, D600, D601 |  | ROHM - SML-P11UT(R) | 402 | Standard LEDs - SMD Red 621nm 2.5mcd 50mW Pd 1.8V Vf | SMT | Fitted | Top
1 | D602 |  | VISHAY - S1A-E3 | DO-214AC | 50V Surface Mount Glass Passivated Rectifier | SMT | Fitted | Top
1 | D603 |  | SMAJ15A-E3/5A |  | Transient Voltage Suppressor, 6.40 to 231 V, 15 V Stand-off Voltage, Uni-Directional, -55 to 155 degC, 2-pin DO-214AC, Pb-Free, Tape and Reel |  | Fitted | Top
1 | F1 |  | LITTELFUSE - 154003.DRT. | 154 Series | Sicherung 3A - NANO2 > 154 OMNI-BLOK - Fuse and Holder Combination | SMT | Fitted | Top
3 | FD1, FD5, FD6 |  | Fiducial Marker 1.0mm | 1.0mm | Passermarke / Fiducial Marker / Kammera-Marke 1.0mm Durchmesser , 500µm Lackfreistellung |  | Fitted | Top
1 | J1 |  | 685119136923 |  | Mini HDMI Type C Receptacle WR-COM, Horizontal, SMT |  | Fitted | Top
1 | J301 |  | 62100421021 |  | SMT Vertical Pin Header WR-PHD, Pitch 1.27 mm, Dual Row, 4 pins |  | Fitted | Top
1 | J500 |  | 629105150521 |  | Micro USB 2.0 Type B Receptacle WR-COM, Horizontal, SMT, with Pegs, High Current at Pin 1 & Pin 5 |  | Fitted | Top
2 | JP1, JP2 |  | Solder Jumper Triple 0402 without Assembly | 0402 Triple | Solder Jumper Triple 0402 without Assembly | SMT | Fitted | Top
3 | JP3, JP4, JP302 |  | Solder Jumper 0402 bestückt | 402 | Solder Jumper 0402 bestückt | SMT | Fitted | Top
2 | JP301, JP303 |  | Solder Jumper 0402 unbestückt | - | Solder Jumper 0402 unbestückt | - | Fitted | Top
3 | L500, L501, L502 |  | DLP11SN900HL2L |  | Chip Common Mode Choke Coil, 1.5 Ohm, 150 mA, -40 to 85 degC, 4-Pin SMD (1210), RoHS, Tape and Reel |  | Fitted | Top
7 | Q300, Q301, Q302, Q303, Q304, Q401, Q600 |  | ON SEMICONDUCTOR - BSS138 | SOT23-3 | MOSFET N-CH 50V 220MA SOT-23 | SMT | Fitted | Top
23 | R251, R252, R300, R301, R302, R303, R304, R305, R306, R307, R312, R314, R316, R317, R318, R320, R504, R511, R515, R516, R517, R605, R606 | 100k | RES 0402 100K 1% 62.5mW | 0402 [1005] | RC0402 series chip resistor with lead-free terminations made by thick film process | SMT | Fitted | Top
9 | R308, R309, R310, R319, R503, R505, R509, R600, R601 | 1k | RES 0402 1K 1% 62.5mW | 0402 [1005] | RC0402 series chip resistor with lead-free terminations made by thick film process | SMT | Fitted | Top
1 | R311 | 47k | RES 0402 47K 1% 62.5mW | 0402 [1005] | RC0402 series chip resistor with lead-free terminations made by thick film process | SMT | Fitted | Top
0 | R315 | 100k | RES 0402 100K 1% 62.5mW | 0402 [1005] | RC0402 series chip resistor with lead-free terminations made by thick film process | SMT | Not Fitted | Top
1 | R401 | 30k | RES 0402 30K 1% 62.5mW | 0402 [1005] | RC0402 series chip resistor with lead-free terminations made by thick film process | SMT | Fitted | Top
1 | R402 | 51 | RES 0402 51R 1% 62.5mW | 0402 [1005] | RC0402 series chip resistor with lead-free terminations made by thick film process | SMT | Fitted | Top
3 | R500, R501, R502 | 10k | RES 0402 10K 1% 62.5mW | 0402 [1005] | RC0402 series chip resistor with lead-free terminations made by thick film process | SMT | Fitted | Top
1 | R506 | 12k | RES 0402 12K 1% 62.5mW | 0402 [1005] | RC0402 series chip resistor with lead-free terminations made by thick film process | SMT | Fitted | Top
1 | R510 | 1,5k | RES 0402 1K5 1% 62.5mW | 0402 [1005] | RC0402 series chip resistor with lead-free terminations made by thick film process | SMT | Fitted | Top
0 | R512, R513, R514 | 10k | RES 0402 10K 1% 62.5mW | 0402 [1005] | RC0402 series chip resistor with lead-free terminations made by thick film process | SMT | Not Fitted | Top
1 | R602 | 13,3k | RES 0402 13K3 1% 62.5mW | 0402 [1005] | RC0402 series chip resistor with lead-free terminations made by thick film process | SMT | Fitted | Top
1 | R603 | 8,25k | RES 0402 8k25 1% 100mW | 402 | 0402 series chip resistor with lead-free terminations made by thick film process | SMT | Fitted | Top
1 | R604 | 324k | RES 0402 324K 1% 62.5mW | 0402 [1005] | RC0402 series chip resistor with lead-free terminations made by thick film process | SMT | Fitted | Top
1 | U300 |  | Raspberry PI - Compute Modul | DDR2-SODIMM | Compute Module SODIMM Pinout for CM3 Lite, also compatible with CM1 and CM3 check Datasheet. | SMT | Fitted | Top
1 | U301 |  | STMICROELECTRONICS - EMIF06-MSD02N16 | Micro QFN 3.5x1.2 16L | 6-line IPAD¿, EMI filter and ESD protection | SMT | Fitted | Top
1 | U302 |  | ESD5384NCTBG |  | 5-Line HDMI Control Line, ESD Protection, 9-Pin WLCSP, Pb-Free, Tape and Reel |  | Fitted | Top
1 | U303 |  | DIODES INCORPORATED - AP2331 | SOT23 | 0.2A Single Channel Current-Limited Load Switch | SMT | Fitted | Top
3 | U500, U502, U503 |  | DIODES INCORPORATED - AP2111MPG-13 | MSOP-8EP | 2A SINGLE CHANNEL CURR ENT-LIMITED POWER SWITCH, high-side power switch for USB | SMT | Fitted | Top
1 | U501 |  | MICROCHIP - USB2534 | SQFN | The USB2534 is a low-power, OEM configurable, MTT (Multi-Transaction Translator) USB 2.0 hub controller with 4 downstream ports and advanced features for embedded USB applications. | SMT | Fitted | Top
0 | U504 |  | MICROCHIP - AT24C04BN-SH-T | 8Y6 | The AT24C04B/08B provides 4096/8192 bits of serial electrically erasable and programmable read-only memory (EEPROM) organized as 512/1024 words of 8 bits each. | SMT | Not Fitted | Top
1 | U600 |  | LTM4622EV#PBF |  | Dual Ultrathin Step-Down DC/DC uModule Regulator, 2.5 A, 3.6 to 20 V, -40 to 125 degC, 25-Pin LGA, RoHS, Tray | SurfaceMount | Fitted | Top
1 | U602 |  | TPS73618DBVR |  | Single Output Low Noise LDO, 400 mA, Fixed 1.8 V Output, 1.7 to 5.5 V Input, with Reverse Current Protection, 5-pin SOT-23 (DBV), -40 to 85 degC, Green (RoHS & no Sb/Br) |  | Fitted | Top
1 | X300 |  | MOLEX - 503182-1853 | microSD Card Connector | 1.09mm Pitch, microSD Memory Card Connector, Ultra Low-Profile, Push-Push Type, 1.45mm Height, Anti-card fly-out | SMT | Fitted | Top
1 | X500 |  | ABM3B-24.000MHZ-B2-T |  | Ceramic SMD Crystal, 24 MHz, +/- 20 ppm, 50 Ohm, -20 to 70 degC, 4-Pin SMD, RoHS, Tape and Reel |  | Fitted | Top

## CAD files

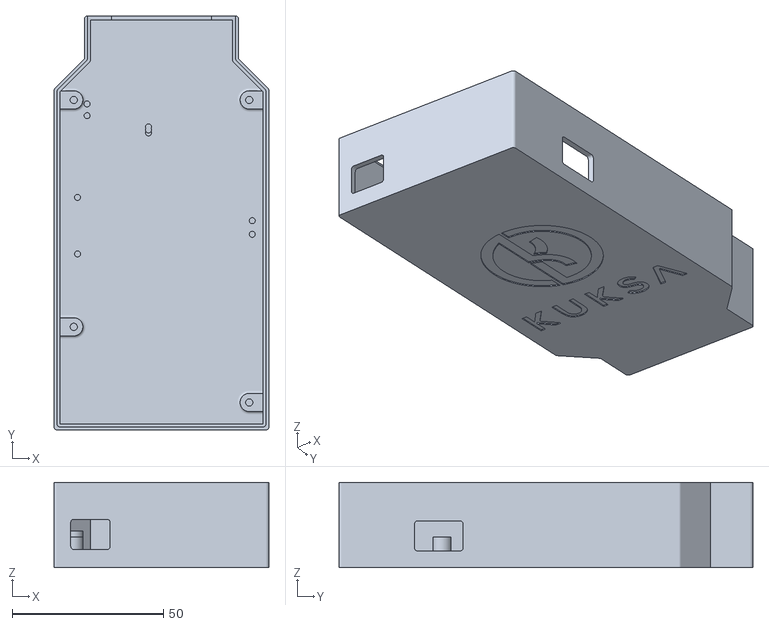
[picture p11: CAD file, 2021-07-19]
Hardware_v1/housing/housing-top.stl
71.0 x 136.9 x 28.2

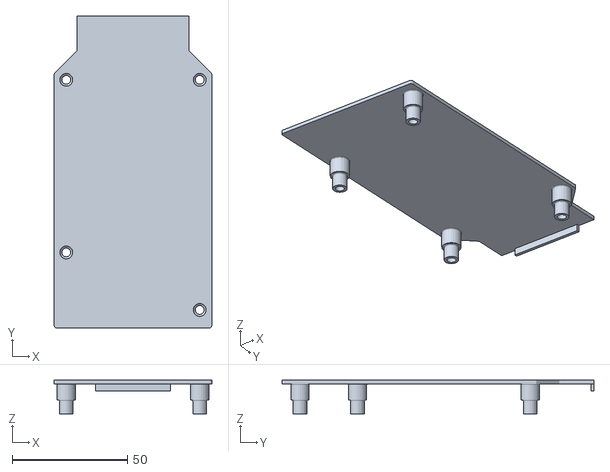
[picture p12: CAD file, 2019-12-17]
Hardware_v1/housing/housing-bottom.stl
68.5 x 135.6 x 14.6

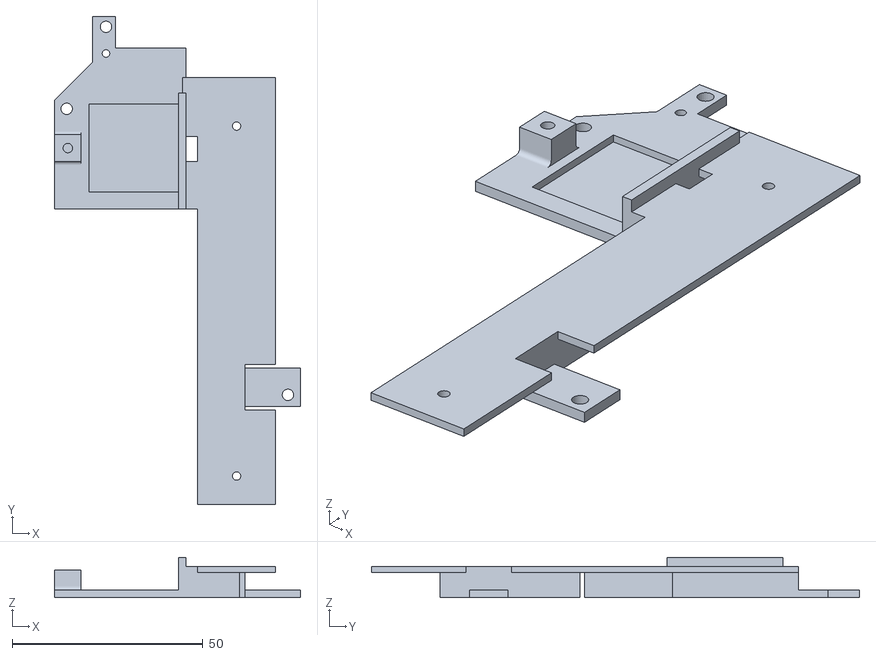
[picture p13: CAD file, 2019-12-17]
Hardware_v1/housing/antenna-bracket-basic.stl
64.5 x 128.1 x 10.5

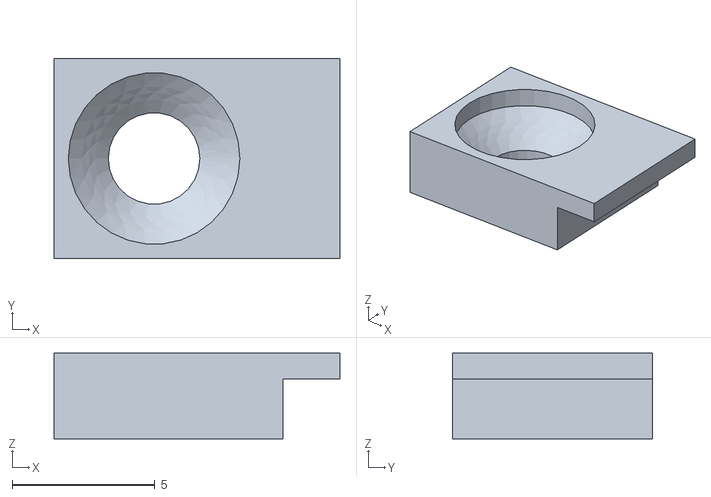
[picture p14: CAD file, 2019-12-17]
Hardware_v1/housing/antenna-bracket-lock.stl
10.0 x 7.00 x 3.00

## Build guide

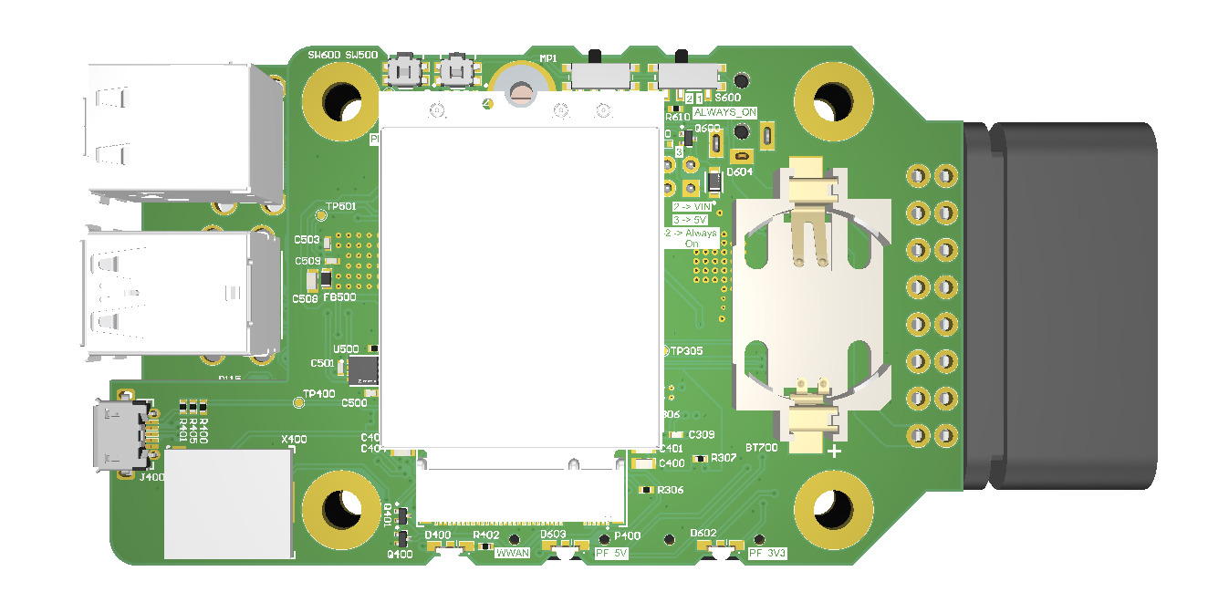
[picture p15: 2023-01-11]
hw_doc/img/CANOPi_3D_FullAssembly_Bot.PNG

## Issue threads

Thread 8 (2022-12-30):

Pick and Place File for PCB Assembly

OpenSourceIronman, 2022-12-30:
I'm ordering PCBs for assembly at https://jlcpcb.com/order and can't seem to find the pick and place file that I assumed would be in EDA directory somewhere near https://github.com/TesCustoms/TesMufflerDongle/tree/main/EDA/PiOBD_CM4_MultiBoard_V1.1/TopBoard/Project%20Outputs%20for%20TopBoard

Linked below is a sample CPL file that JCL PCB provided:
https://www.icloud.com/iclouddrive/050_UZ1zaG_tQxW3B6V0IZN7w#JLCSMT_Sample_CPL1

eriksven, 2023-01-02:
Hi @OpenSourceIronman , the team which worked on the hardware dongle is currently on their Christmas and New Years break. So I am afraid that we will not have a good answer to your question until next week. Sorry about that.

SebastianSchildt, 2023-01-02:
What @eriksven said. I will try to reach out to our hw gurus and see what we can do. Might take some days though. What I can say, the reason, we did not notice this particular information missing is, that for our first production  run our "Pick & place machines" where human-based...

OpenSourceIronman, 2023-01-02:
Thanks guys! I will also probably hand solder paste and then drag solder the first two PCBs myself 🤓

But then plan to make ~100 units in May 2023, 400 more in Aug 2023, and then final 1500 more in Oct 2023.

https://docs.google.com/presentation/d/1vmfBdLqMhj65gBI4U_X0QDvzo5LgiAgdK-cK7LWeqZQ/edit

SebastianSchildt, 2023-01-11:
If you really manage to make them (sourcing is a bit difficult for some of the components), I am pretty sure you could also have customers outside your specific project.

We saw quite a bit interest around the "Software Defined Vehicle" Open Source community, to use this for various projects, but so far we did not manage pre-financing a complete batch.

So if you do manage to move forward with this design, or something based on it, be sure to ping us, or advertise here https://sdv.eclipse.org

At least it might help you getting some additional volume 🤓

We updated the manufacturing files to include Pick&Place, fresh Gerber export and some other documentation improvements. We should(tm) not have missed any vital files and PCB should not have  been changed, but just to be sure, previous master is tagged here: https://github.com/eclipse/kuksa.hardware/tree/hardware2_v11

OpenSourceIronman, 2023-01-11:
I really appreciate the update. I will double check everything and get back to the team in 7 to 10 days.

Closed 2023-01-11.

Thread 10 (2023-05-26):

Why there four BOM files？

aricwang88, 2023-05-26:
We're planing to mass produce the PCB board, found four BOM files. Which files to be used? Please add more comments, or remove unused files.

aricwang88, 2023-05-26:
<html><body>
<!--StartFragment-->

Bill of Materials-Layer separated-CANOPi_BaseBoard(BASIC).xlsx(File) | More info in Documentation, BOM xls and Pick and Place Files |  
-- | -- | --
 

<h3><div class="react-directory-truncate" title="Bill of Materials-all-CANOPi_TopBoard(BASIC).xlsx" aria-label="Bill of Materials-all-CANOPi_TopBoard(BASIC).xlsx"><a aria-describedby="item-type-16" class="Link--primary" href="https://github.com/eclipse/kuksa.hardware/blob/main/manufacturing/BOM/Bill%20of%20Materials-all-CANOPi_TopBoard(BASIC).xlsx">Bill of Materials-all-CANOPi_TopBoard(BASIC).xlsx</a></div></h3><!--EndFragment-->
</body>
</html>[Bill of Materials-Layer separated-CANOPi_BaseBoard(BASIC).xlsx](https://github.com/eclipse/kuksa.hardware/blob/main/manufacturing/BOM/Bill%20of%20Materials-Layer%20separated-CANOPi_BaseBoard(BASIC).xlsx)
(File)

[More info in Documentation, BOM xls and Pick and Place Files](https://github.com/eclipse/kuksa.hardware/commit/fbc9e568fca608d3130e48750aaae04275a14b98)

[Bill of Materials-Layer separated-CANOPi_TopBoard(BASIC).xlsx](https://github.com/eclipse/kuksa.hardware/blob/main/manufacturing/BOM/Bill%20of%20Materials-Layer%20separated-CANOPi_TopBoard(BASIC).xlsx)
(File)

[More info in Documentation, BOM xls and Pick and Place Files](https://github.com/eclipse/kuksa.hardware/commit/fbc9e568fca608d3130e48750aaae04275a14b98)

[Bill of Materials-all-CANOPi_BaseBoard(BASIC).xlsx](https://github.com/eclipse/kuksa.hardware/blob/main/manufacturing/BOM/Bill%20of%20Materials-all-CANOPi_BaseBoard(BASIC).xlsx)
(File)

[More info in Documentation, BOM xls and Pick and Place Files](https://github.com/eclipse/kuksa.hardware/commit/fbc9e568fca608d3130e48750aaae04275a14b98)

[Bill of Materials-all-CANOPi_TopBoard(BASIC).xlsx](https://github.com/eclipse/kuksa.hardware/blob/main/manufacturing/BOM/Bill%20of%20Materials-all-CANOPi_TopBoard(BASIC).xlsx)

SebastianSchildt, 2023-05-26:
Hi Aric, let me try to sort this out for you (maybe we should add a readme).

There are 4 xls Files in https://github.com/eclipse/kuksa.hardware/tree/main/manufacturing/BOM

as you have probably noticed, a CANOPI is composed of two PCBs "TopBoard" and "BaseBoard" that are stacked together.

So https://github.com/eclipse/kuksa.hardware/blob/main/manufacturing/BOM/Bill%20of%20Materials-all-CANOPi_TopBoard(BASIC).xlsx contains the BOM for all components on TopBoard and https://github.com/eclipse/kuksa.hardware/blob/main/manufacturing/BOM/Bill%20of%20Materials-all-CANOPi_BaseBoard(BASIC).xlsx everything for the baseboard.

So do build one complete Canoi parts form both are needed

Now you may have noticed the "layer-seperated" files, those have an extra column showing whether a specific part goes to top or bottom of the PCB. The files have more lines, because then some components are listed twice.

For example in line 22 of https://github.com/eclipse/kuksa.hardware/blob/main/manufacturing/BOM/Bill%20of%20Materials-all-CANOPi_TopBoard(BASIC).xlsx you have

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

while the same component in https://github.com/eclipse/kuksa.hardware/blob/main/manufacturing/BOM/Bill%20of%20Materials-Layer%20separated-CANOPi_TopBoard(BASIC).xlsx is in lines 6 and 7

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

because 6 resistors of that type are place on bottom of the PCB, 7 on top, leading to a total of 13 for that board, as you saw in the other file.

Hope that makes sense to you. If you just want to find out what parts are needed for one CANOPi, ignore the "Layer-separated" files and just combine the other two files

aricwang88, 2023-05-30:
I also hope to custom a BOX, what's the recommended size ?

aricwang88, 2023-05-30:
Please help list the , CM4 configuration,(4G 8G RAM, with eMMC or without eMMC),  and LTE module detail modle.

SebastianSchildt, 2023-05-30:
> I also hope to custom a BOX, what's the recommended size ?

Currently we have no 3D model for a suitable case. In the PDFs in hw_doc you can find renderings, for reference the width of the PCB (short side) is 55 mm.

SebastianSchildt, 2023-05-30:
> Please help list the , CM4 configuration,(4G 8G RAM, with eMMC or without eMMC), and LTE module detail modle.

Not sure I get the question. Any CM4 is supported. Usually for experimentation versions without eMMC (i.e. they boot from SD Card) are easier, becasue for alternating between flashing and running eMMC modules you need to always change a hard to mount jumper (see here https://github.com/eclipse/kuksa.hardware/blob/main/sw_doc/flash-emmc.md or remove the CM4 and flas it e.g. in the official Raspberrry IO Baord). furthermore, not matter how you flash the eMMC version, notice that flashing them is SLOW, so being able to switch between SD cards is much faster.

Due to technical reasons any CM4 with eMMC can NOT use an external SD Card (this is not a CANOPi limitation, but a general CM4 limitation, that holds true for all CM4 carrier boards)

RAM: All variants work, depnding on requriements. For some "SDV-like" things with containers I would suggest using a tleast a 4GiB version

Also the CM4 version with integrated WiFi are helpful (as there is not other network port on the CANOPi), but it works without as well. The CM4 versions with WiFi do not need an external antenna, as they have a PCB antenna, so it is pretty plug and play.

For LTE module any Linux supported M.2 module should work (had success with a Sierra Wireless EM7455 and some  "unknown" Huawei card harvested from an old laptop). In any case, if it works on a Laptop with e.g. Ubuntu, most likely it works on CANOPi as well.

aricwang88, 2023-05-31:
How much each piece of STN2120 chip, we're struggling with order the chip? Or recommended price ?

SebastianSchildt, 2023-05-31:
Hi,
STN2120 is a bit of a challenge. It was over 5 usd a pice (but we only ordered small quantities).

Main issue is, there is no second supplier.  I suggest contacting https://www.obdsol.com/ (the manufacturer) directly. Depending on their availability maybe some of their other variants may be available, if pin compatible (not sure)

CanoPi itself can boot without OBD chip as well, however it is one of the most accessible features for developers,to get data from OBD directly by just plugging the dongle in without having to „cut CAN Lines“. So just leaving it out is probably not a good option

Theroetically an ELM327 (clone) could be used, but that demands a change in PCB Layout, i.e. changing the Altium files. While the STN are software compatible with ELM327, they are not drop in replacements from hw layout perspective. We have so far never looked into this.

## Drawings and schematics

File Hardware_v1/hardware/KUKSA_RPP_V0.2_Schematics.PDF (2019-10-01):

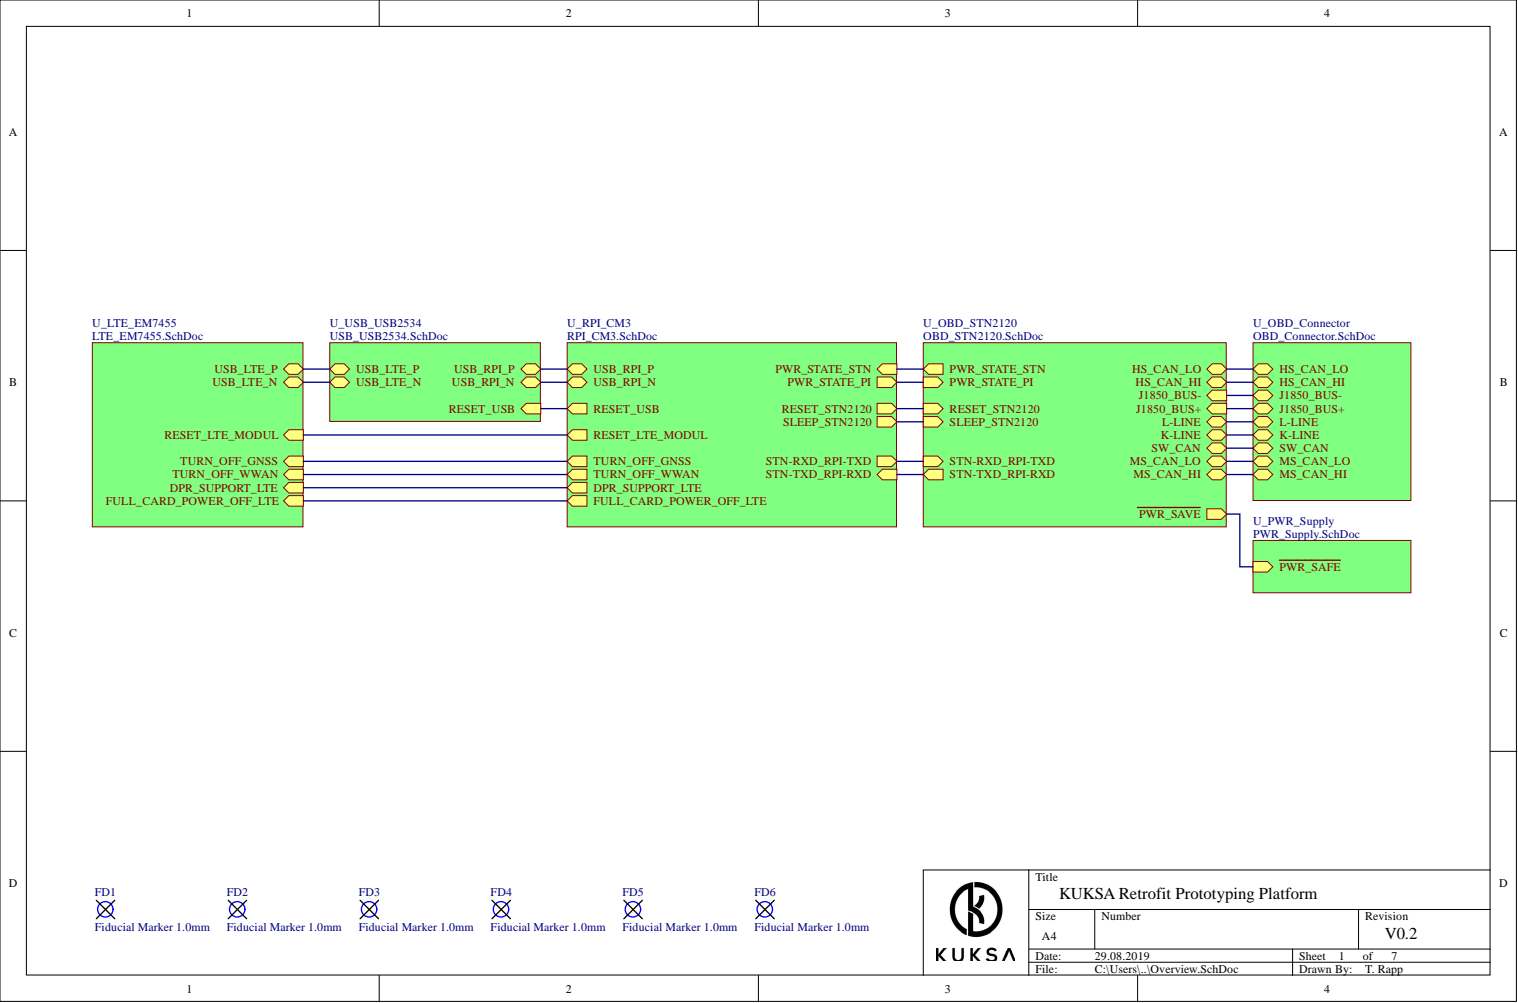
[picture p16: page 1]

Title
KUKSA Retrofit Prototyping Platform

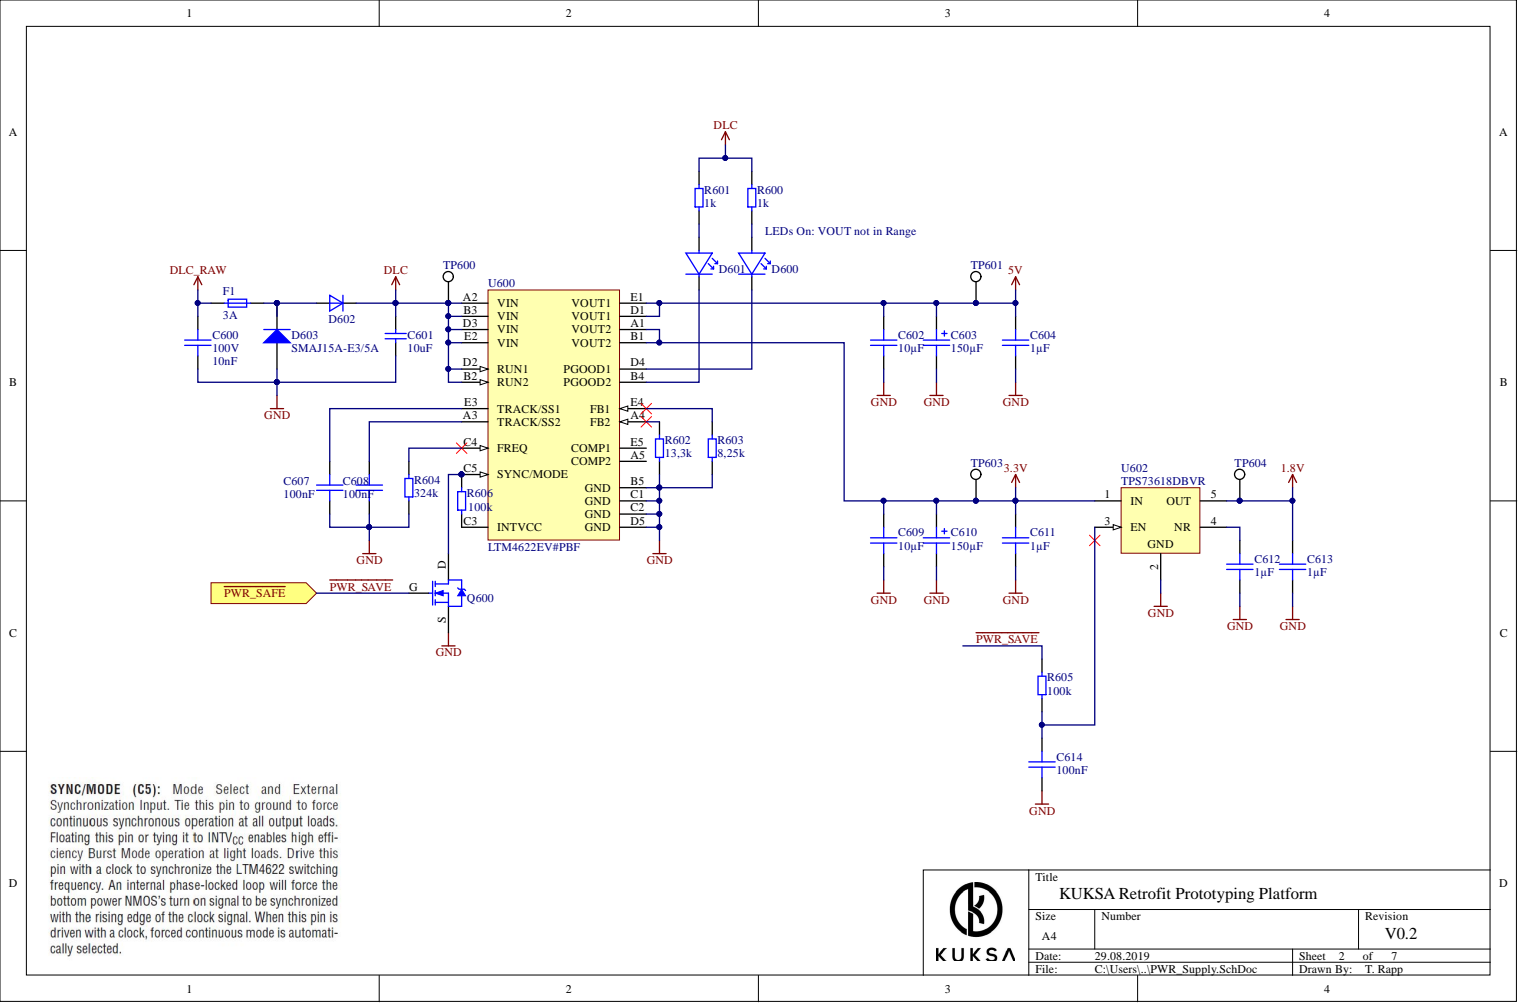
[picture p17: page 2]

LEDs On: VOUT not in Range

FREQ C4

INTVCC C3

Title
KUKSA Retrofit Prototyping Platform

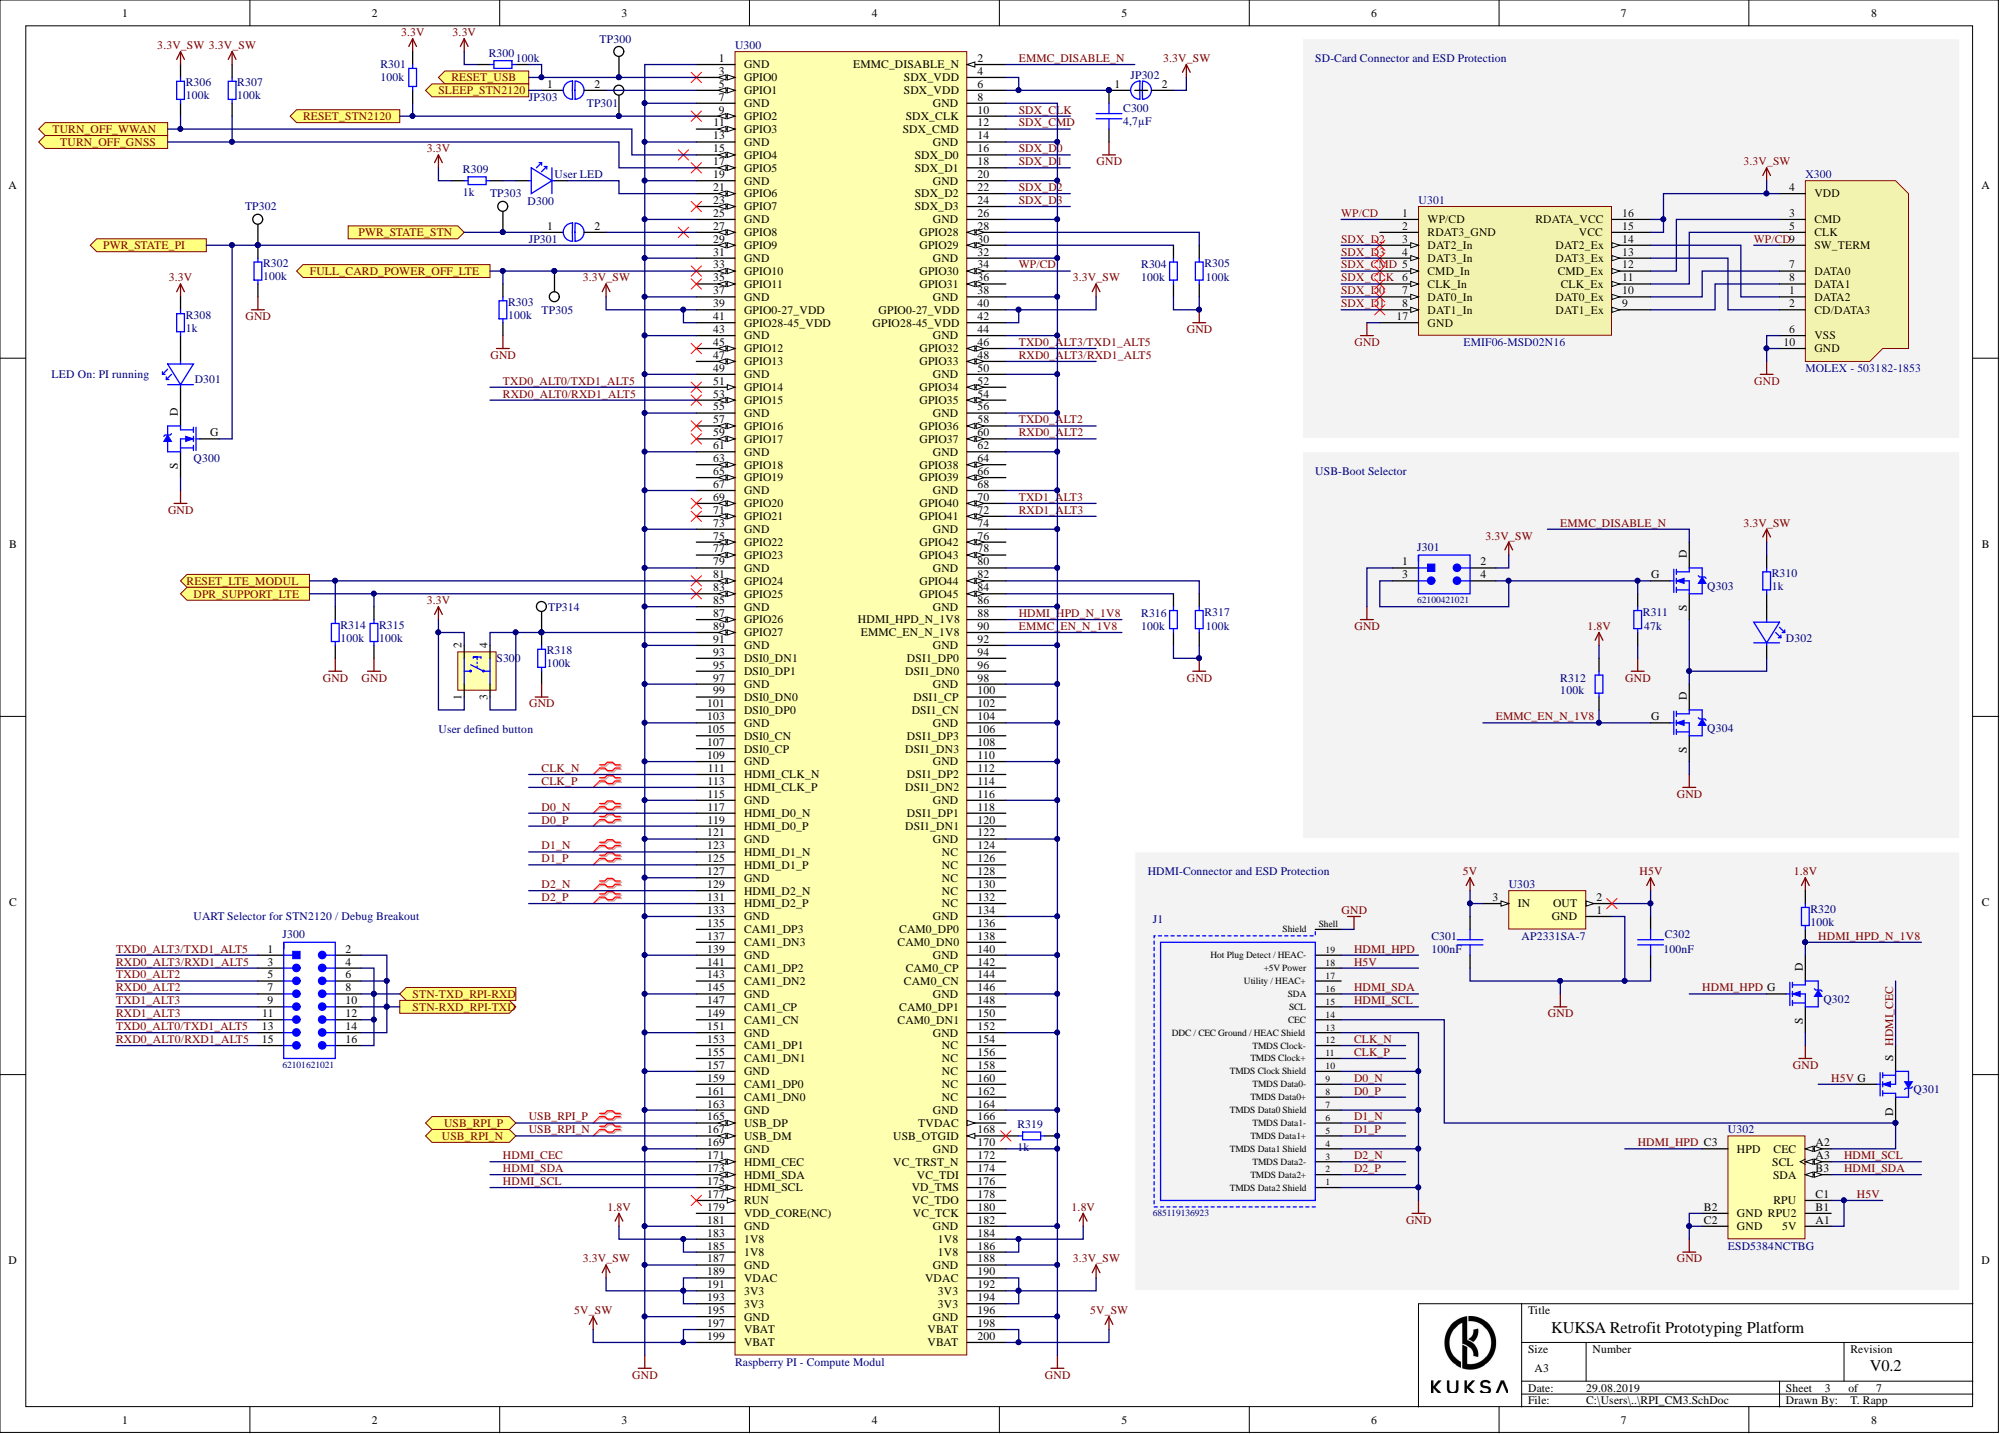
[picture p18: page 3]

R3 0 9 | U ser L E D | 1 9

5 5 | 5 6
5 7 | 5 8 T X D 0 _

8 1 | 8 2
8 3 | 8 4

1 8 9 | 1 9 0
1 9 1 | 1 9 2
1 9 3 | 1 9 4

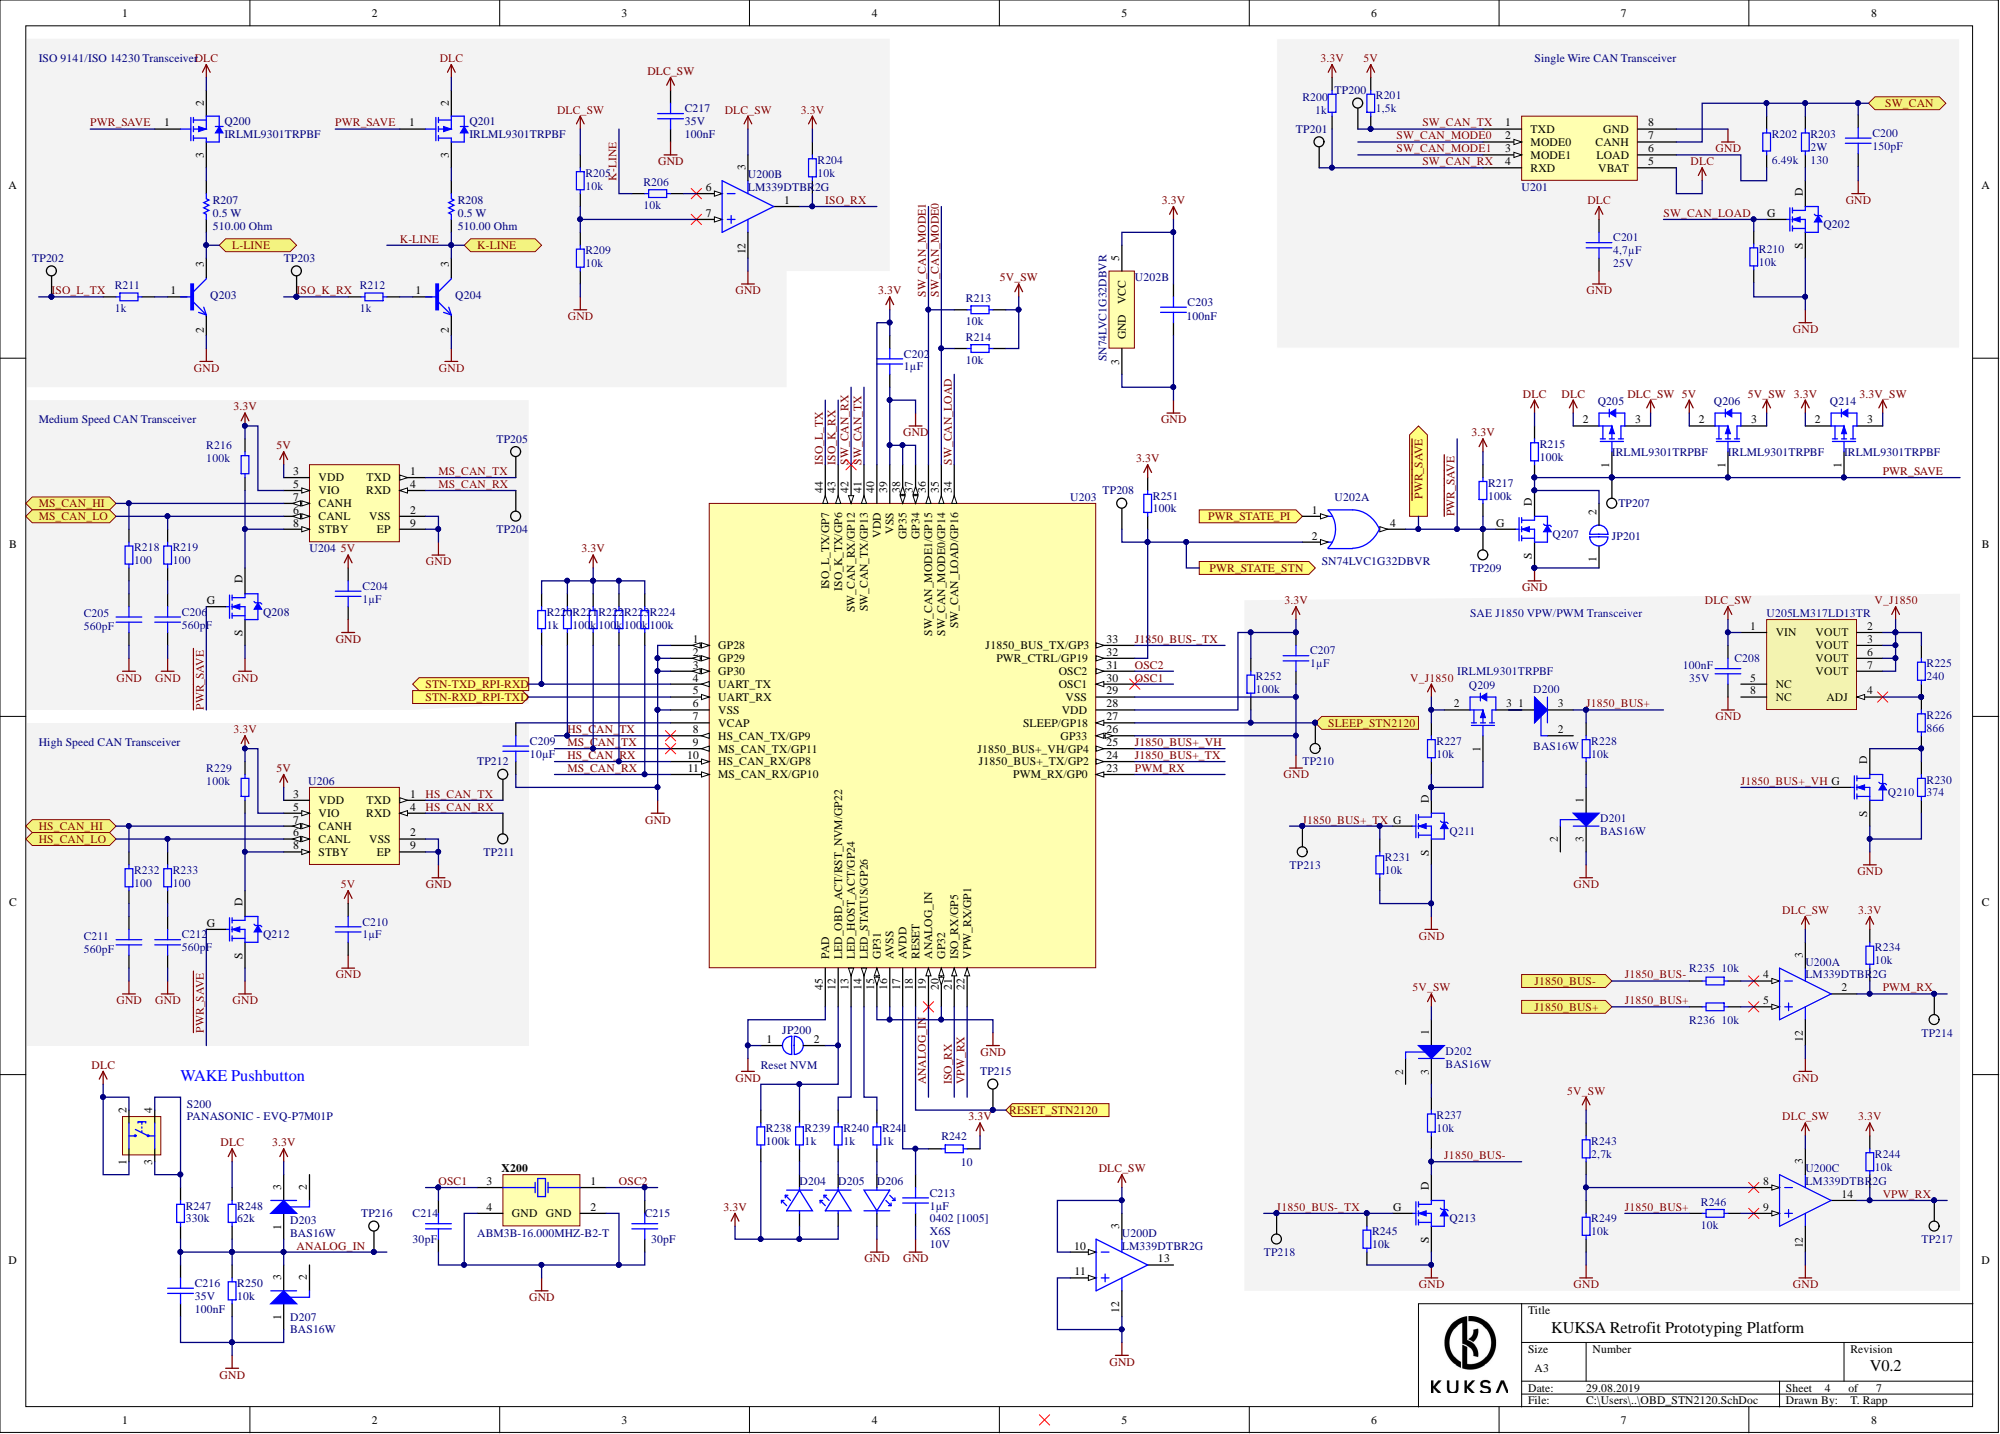
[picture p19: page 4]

Single Wire CAN Transceiver

Medium Speed CAN Transceiver

SAE J1850 VPW/PWM Transceiver

GP30 3 | OSC2
UART_TX 4 | OSC1
UART_RX 5
VSS 6

High Speed CAN Transceiver

Title
KUKSA Retrofit Prototyping Platform

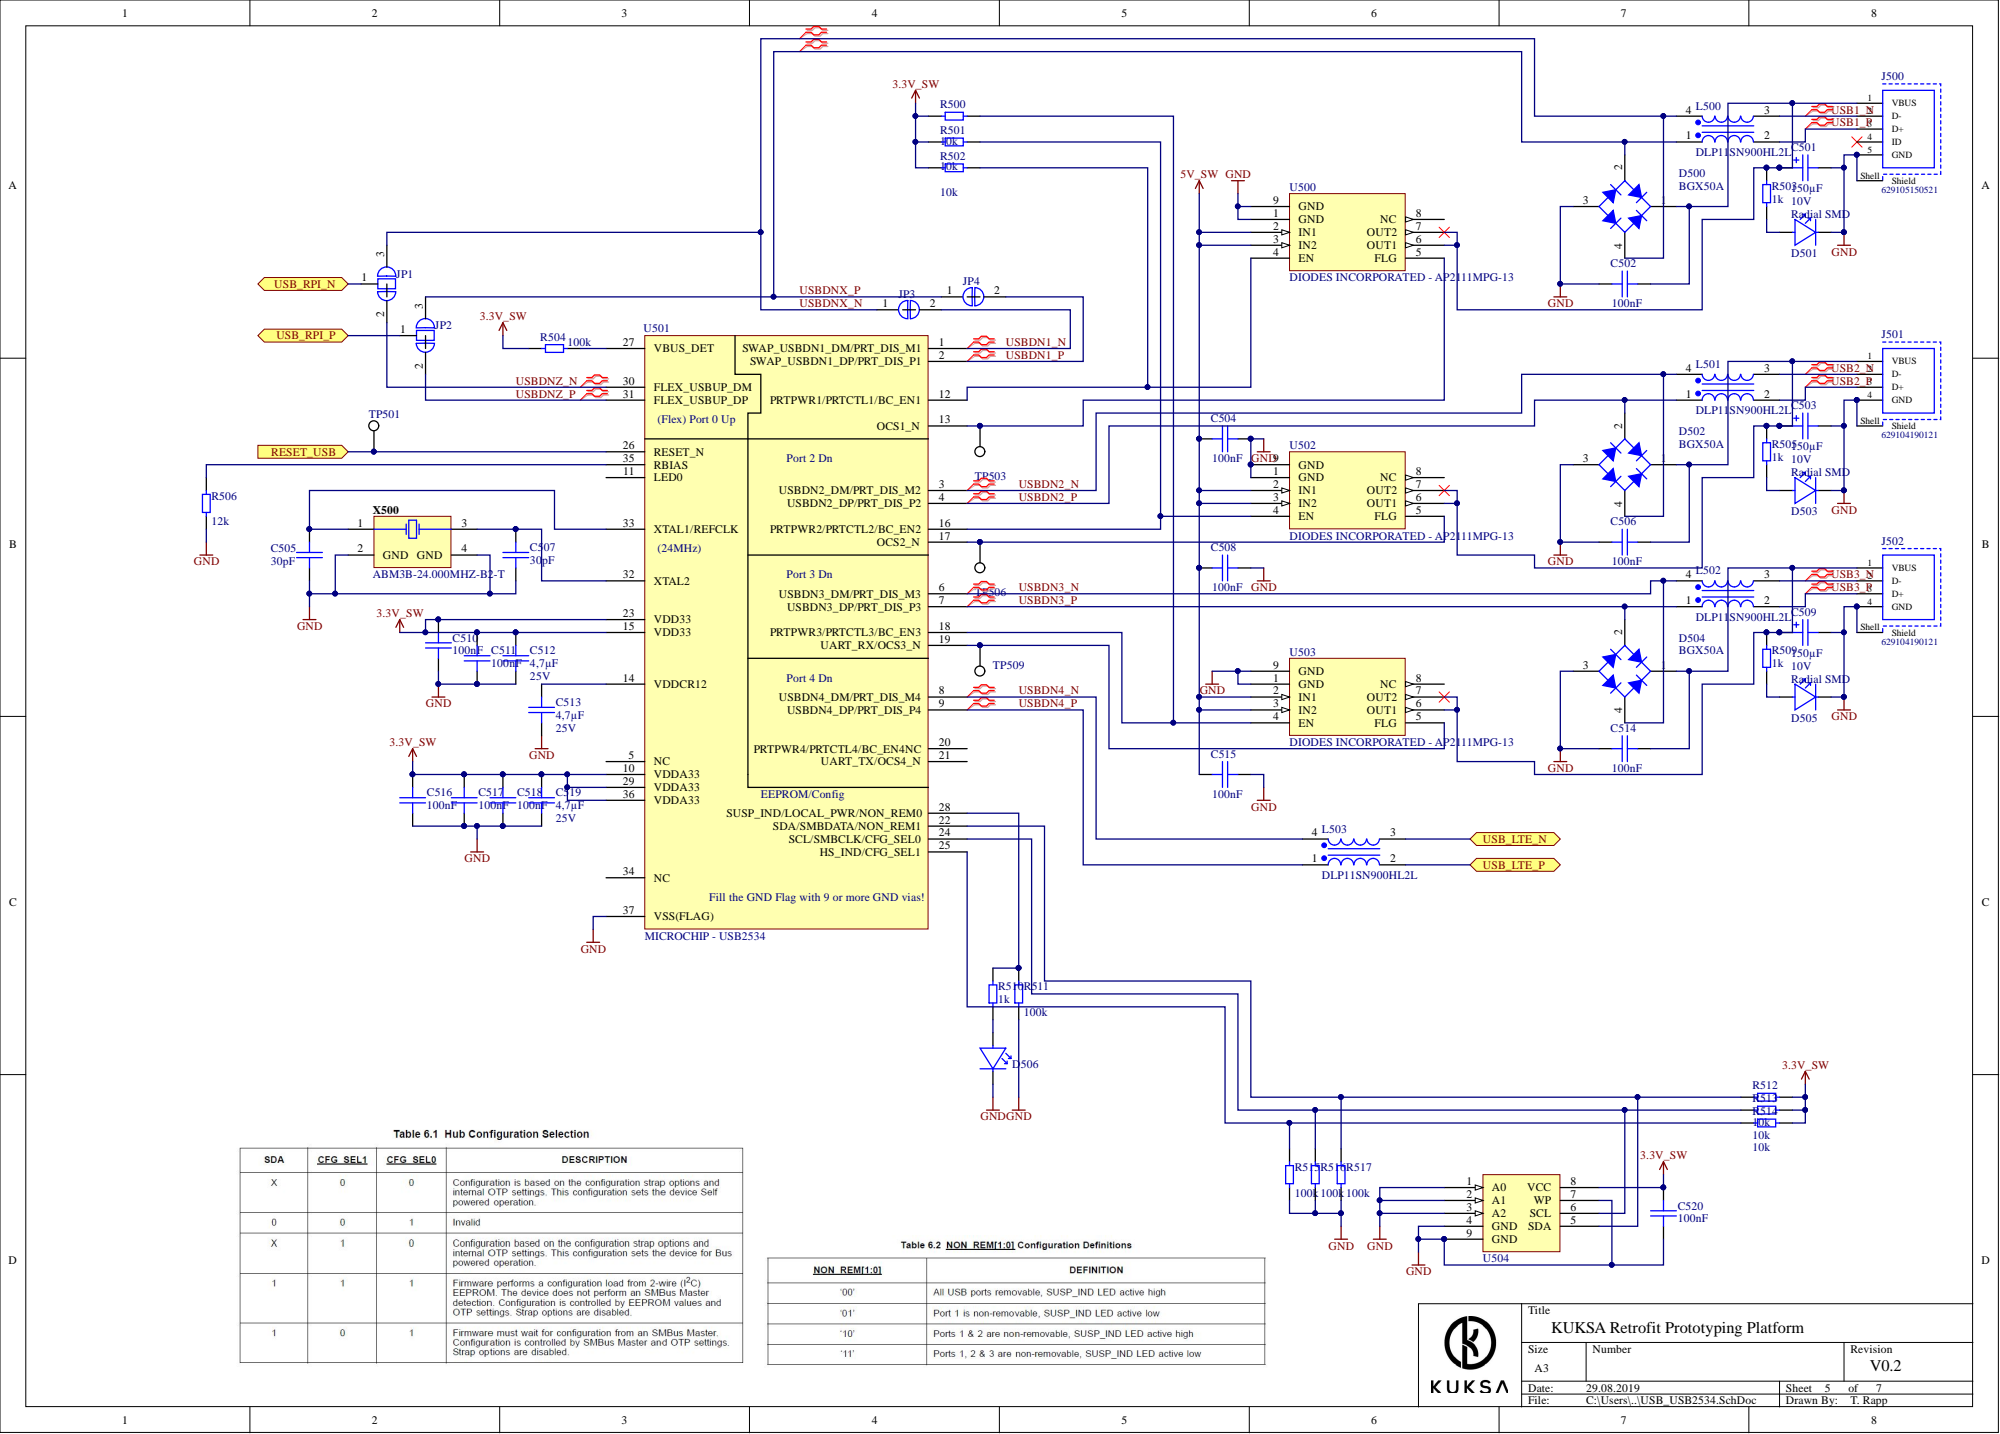
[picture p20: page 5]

Fill the GND Flag with 9 or more GND vias!

GND 9

Title
KUKSA Retrofit Prototyping Platform

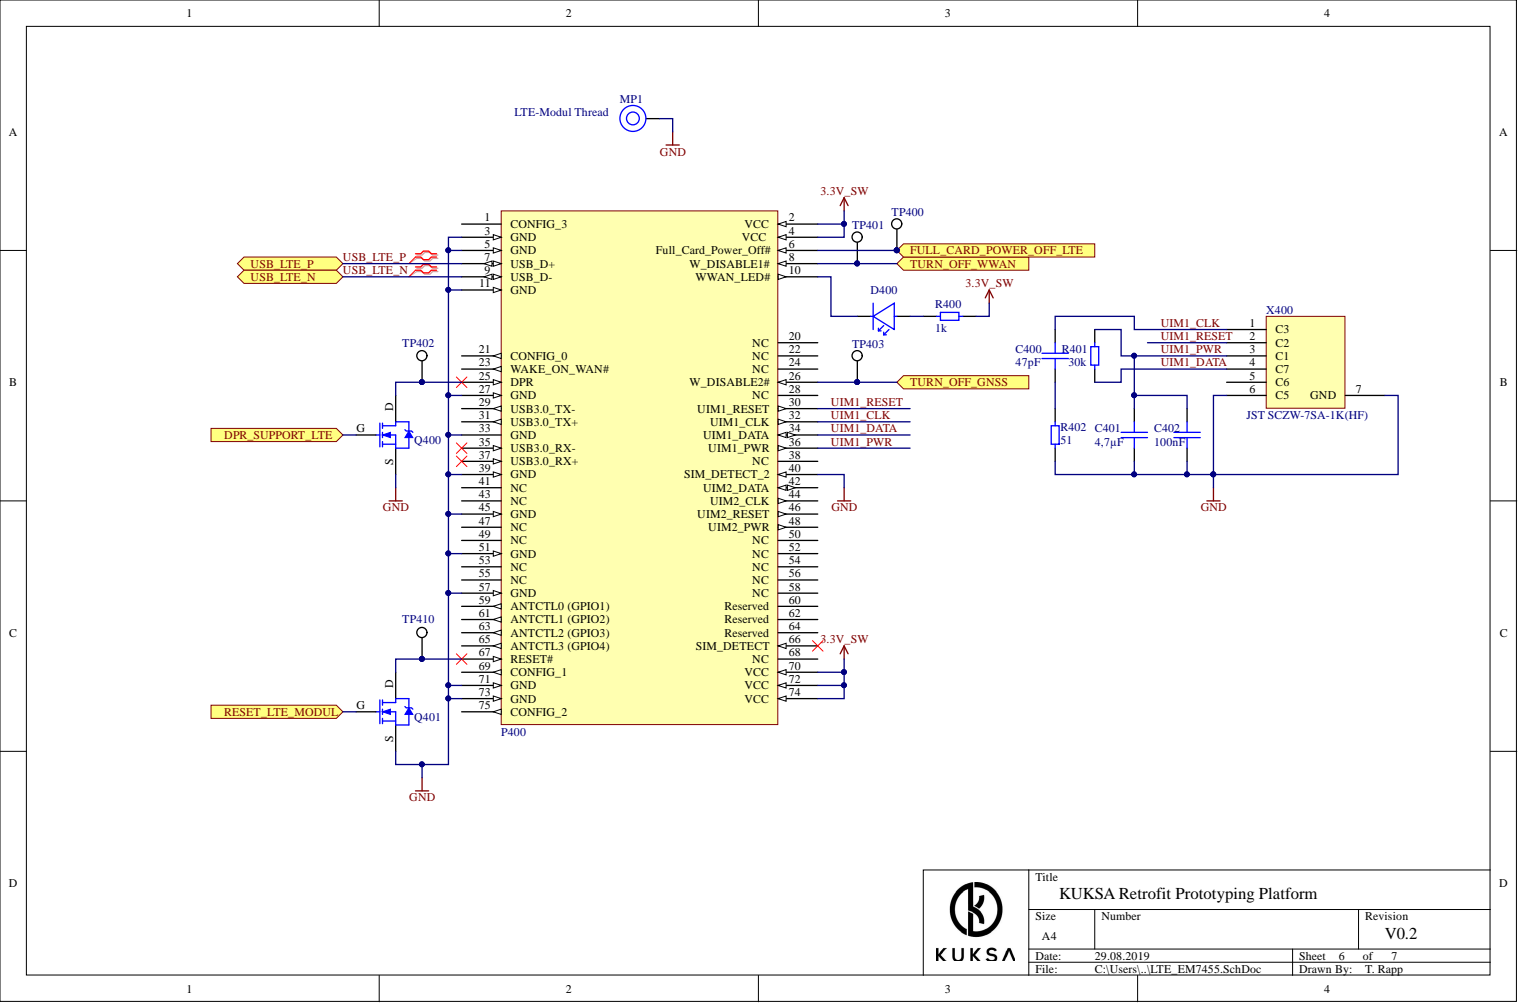
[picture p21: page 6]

UIM1_RESET | | C2 2 C1 3

UIM1_DATA | C7 4

Title
KUKSA Retrofit Prototyping Platform

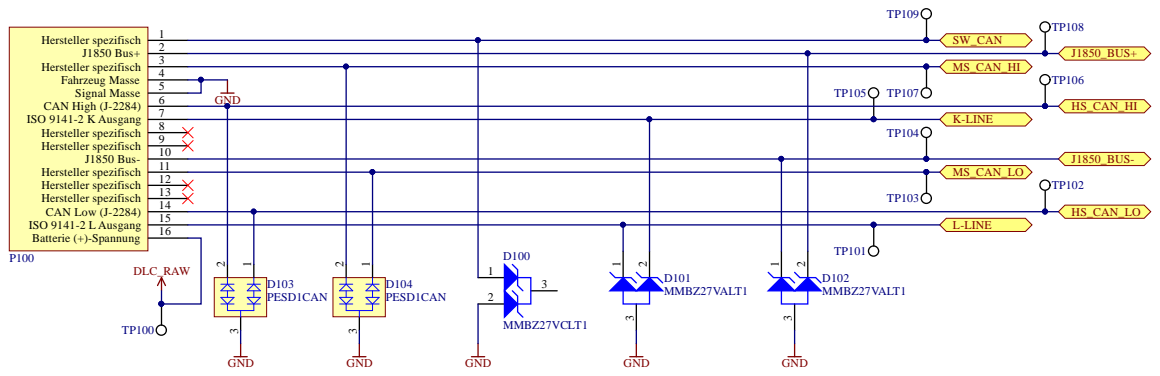
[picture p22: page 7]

4 D | | TP1 0 5 TP1 0 7
5 | G N

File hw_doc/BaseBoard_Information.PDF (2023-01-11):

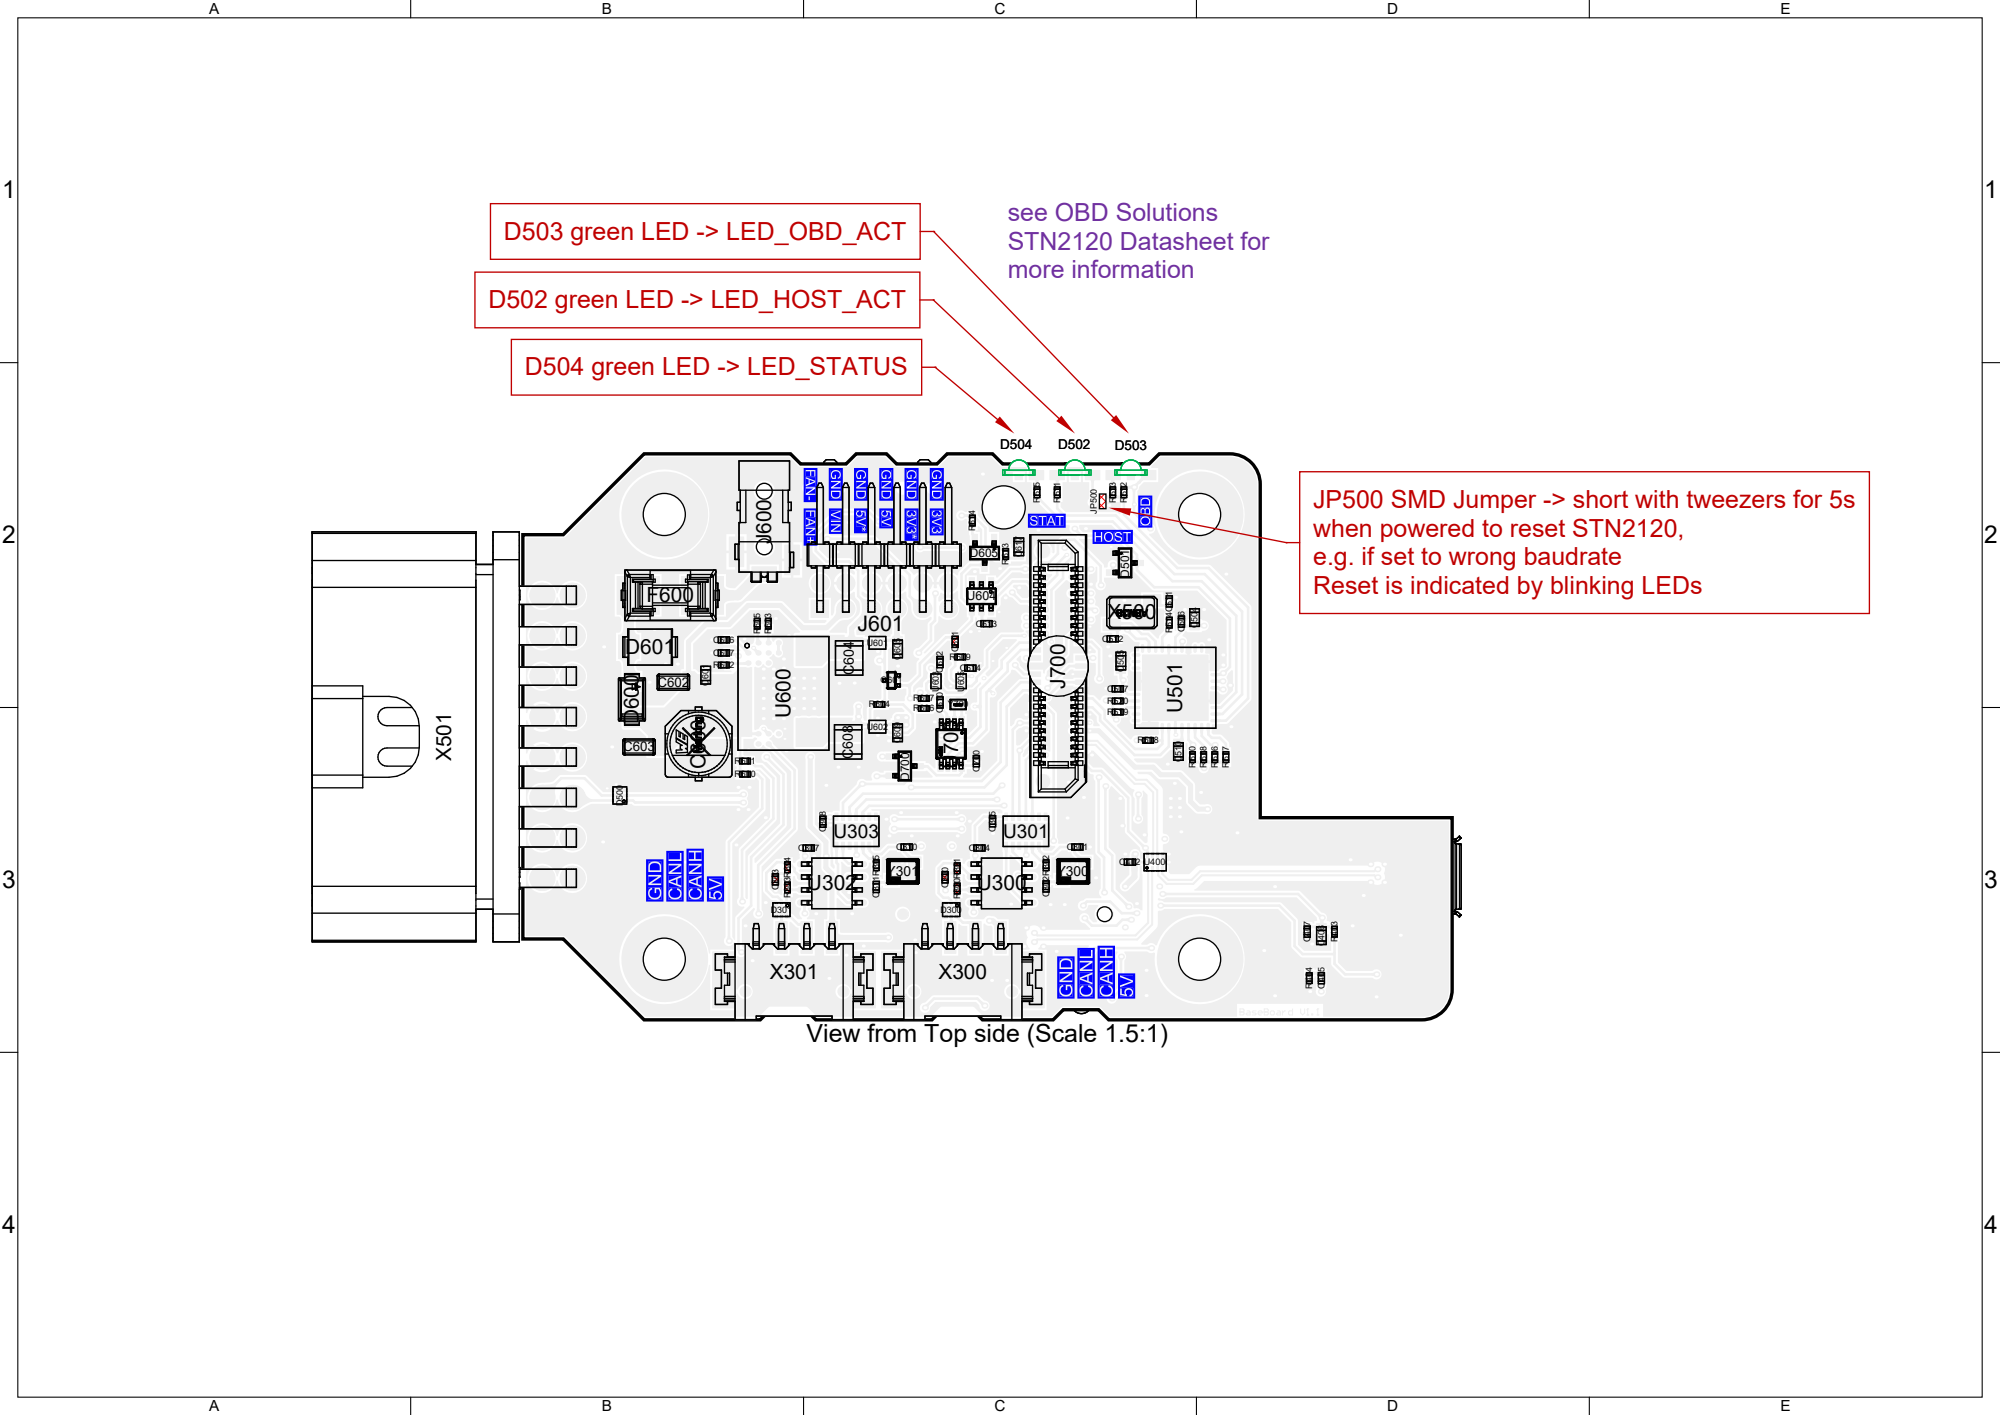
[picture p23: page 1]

JP500 SMD Jumper -> short with tweezers for 5s
when powered to reset STN2120,
e.g. if set to wrong baudrate
Reset is indicated by blinking LEDs

View from Top side (Scale 1.5:1)

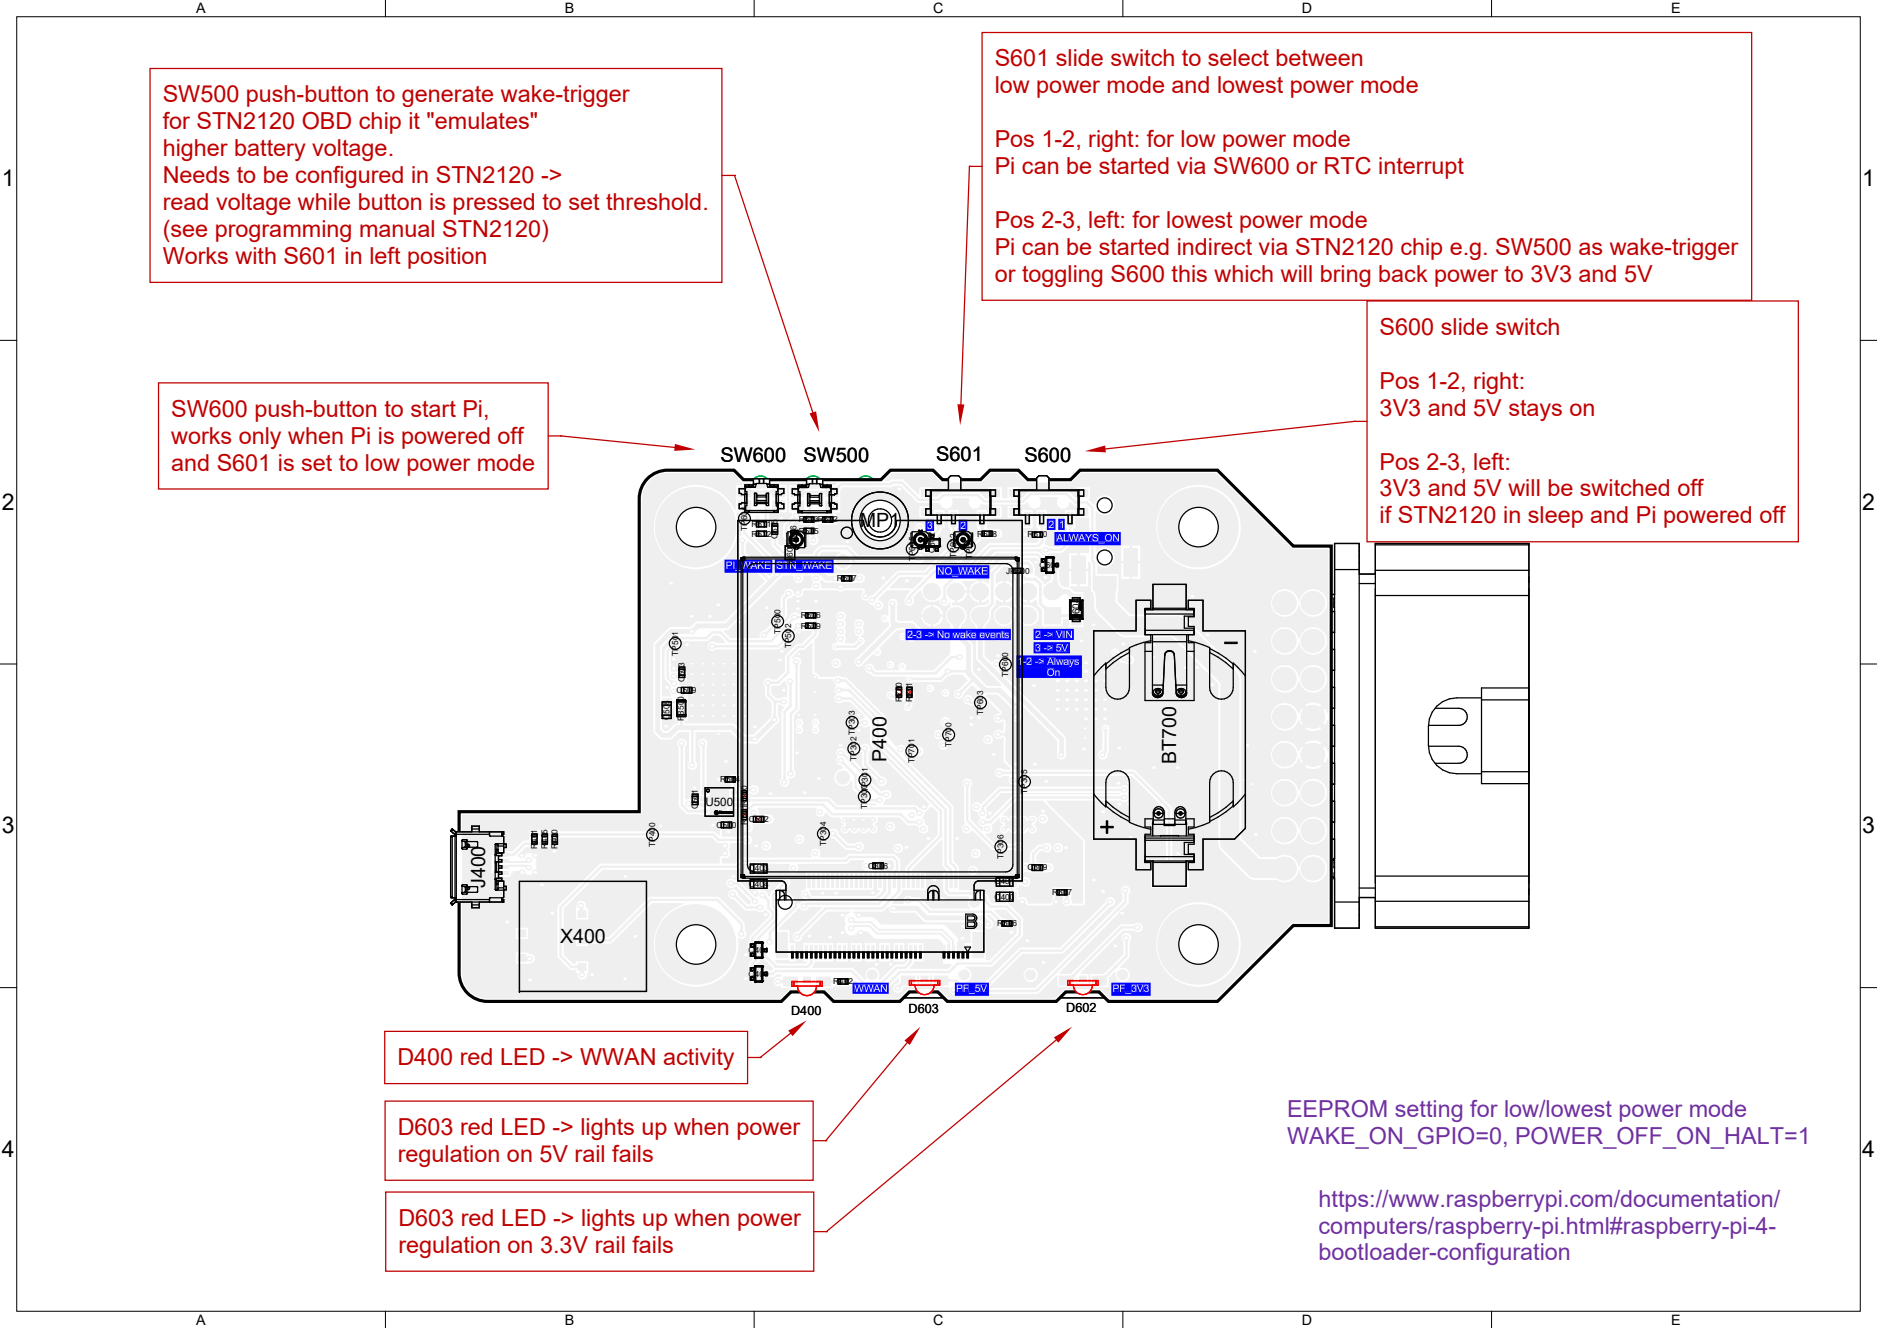
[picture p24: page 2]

S601 slide switch to select between
low power mode and lowest power mode

SW500 push-button to generate wake-trigger
for STN2120 OBD chip it "emulates"
higher battery voltage.
Needs to be configured in STN2120 ->
read voltage while button is pressed to set threshold.
(see programming manual STN2120)
Works with S601 in left position

Pos 1-2, right: for low power mode
Pi can be started via SW600 or RTC interrupt

Pos 2-3, left: for lowest power mode
Pi can be started indirect via STN2120 chip e.g. SW500 as wake-trigger
or toggling S600 this which will bring back power to 3V3 and 5V

SW600 push-button to start Pi,
works only when Pi is powered off
and S601 is set to low power mode

Pos 2-3, left:
3V3 and 5V will be switched off
if STN2120 in sleep and Pi powered off

D400 red LED -> WWAN activity

EEPROM setting for low/lowest power mode
WAKE_ON_GPIO=0, POWER_OFF_ON_HALT=1

D603 red LED -> lights up when power
regulation on 5V rail fails

https://www.raspberrypi.com/documentation/
computers/raspberry-pi.html#raspberry-pi-4-
bootloader-configuration

regulation on 3.3V rail fails

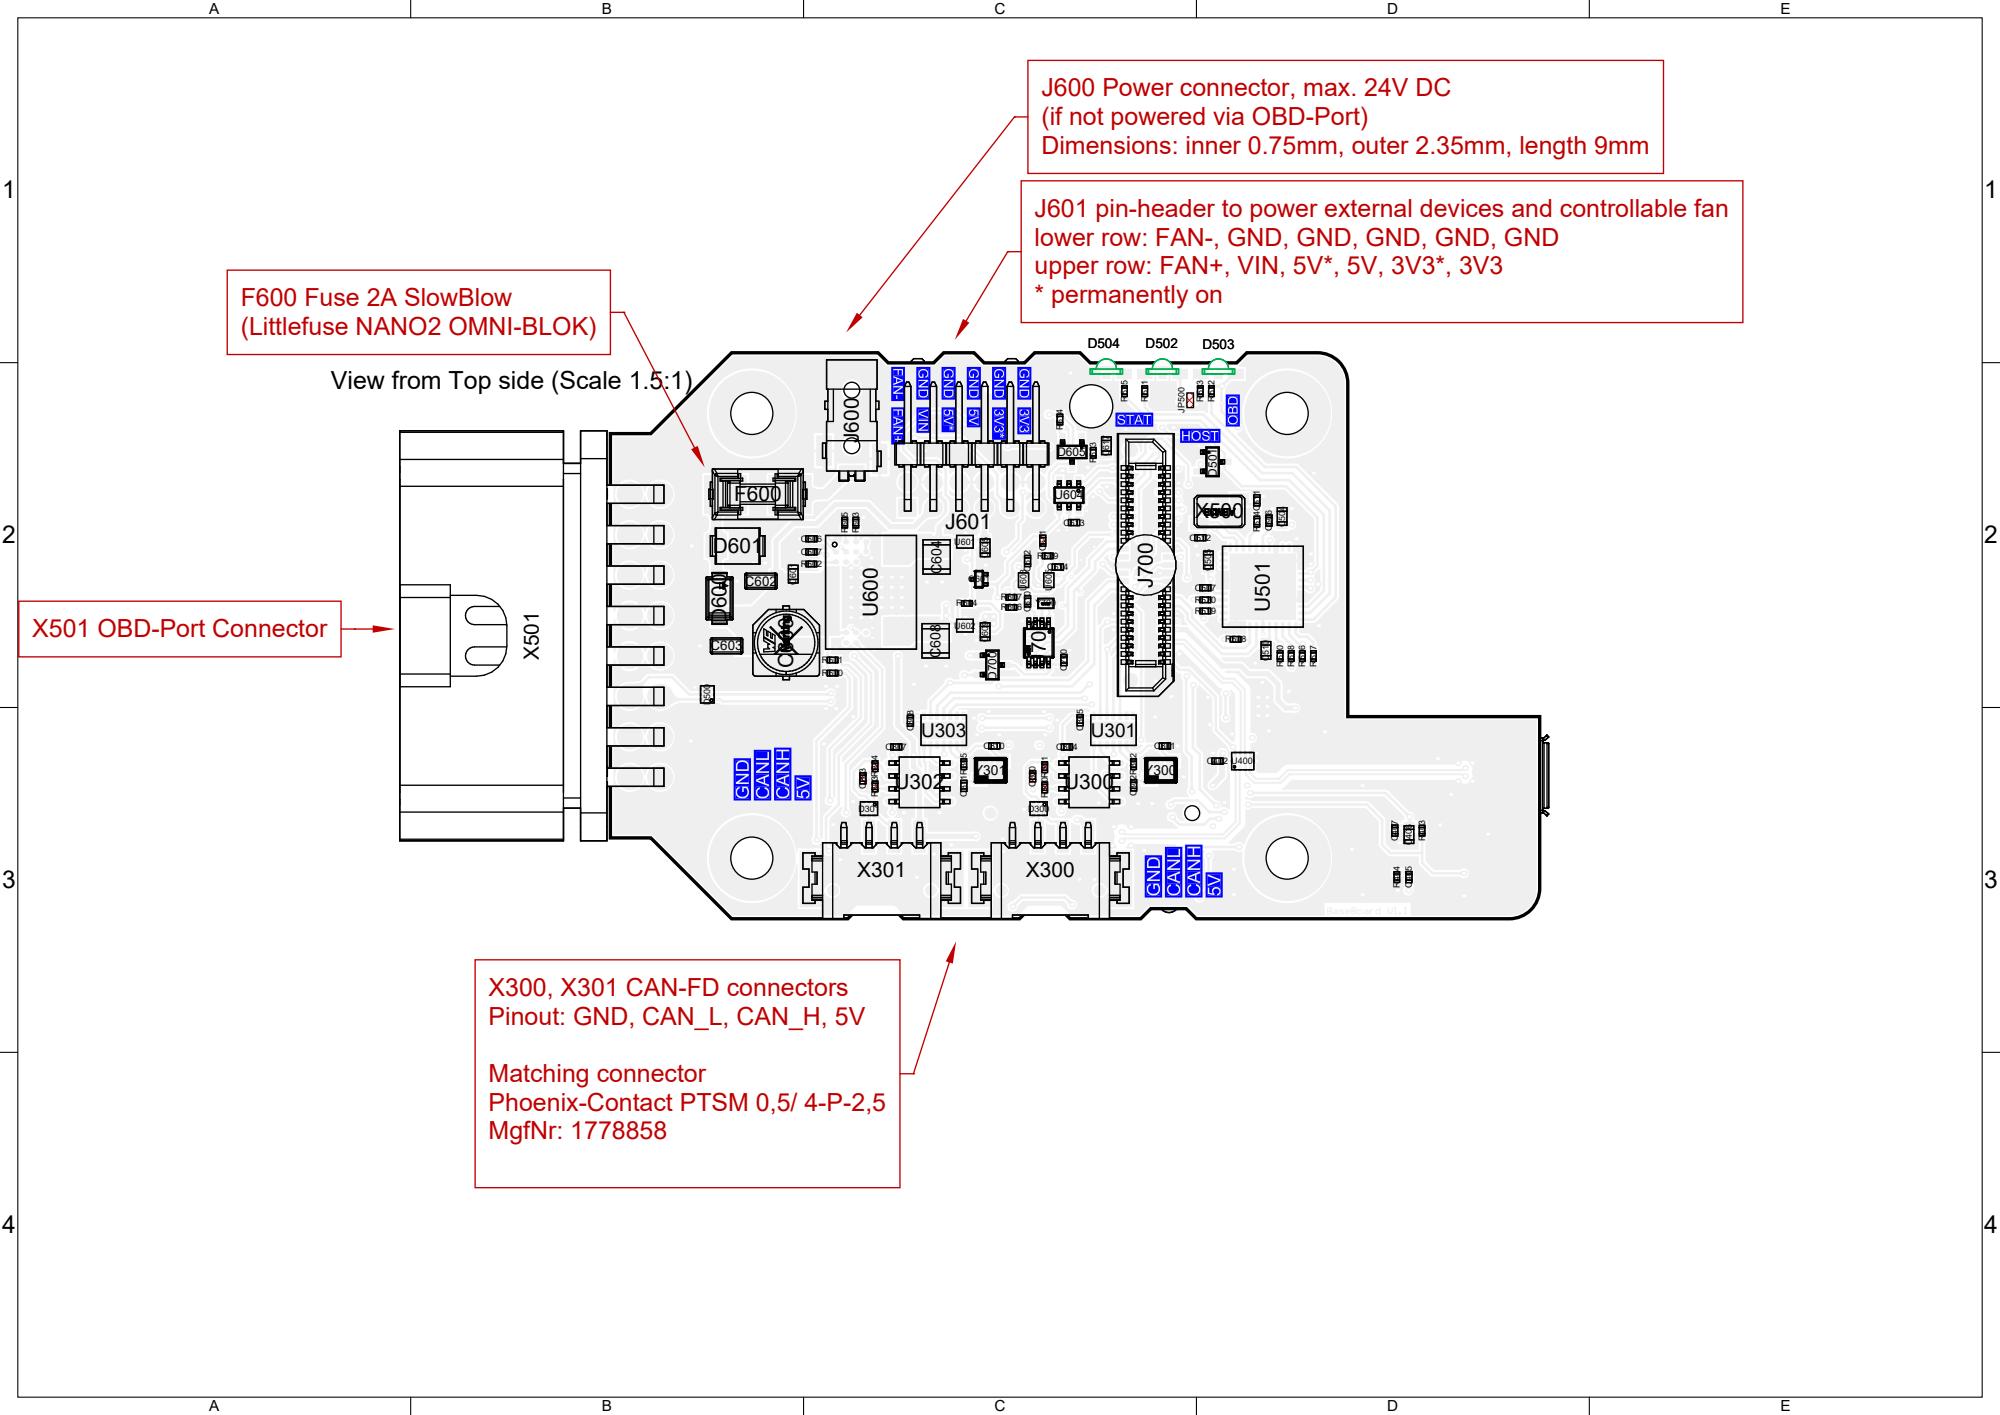
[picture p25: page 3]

J600 Power connector, max. 24V DC
(if not powered via OBD-Port)
Dimensions: inner 0.75mm, outer 2.35mm, length 9mm

J601 pin-header to power external devices and controllable fan
lower row: FAN-, GND, GND, GND, GND, GND
upper row: FAN+, VIN, 5V*, 5V, 3V3*, 3V3
* permanently on

View from Top side (Scale 1.5:1)

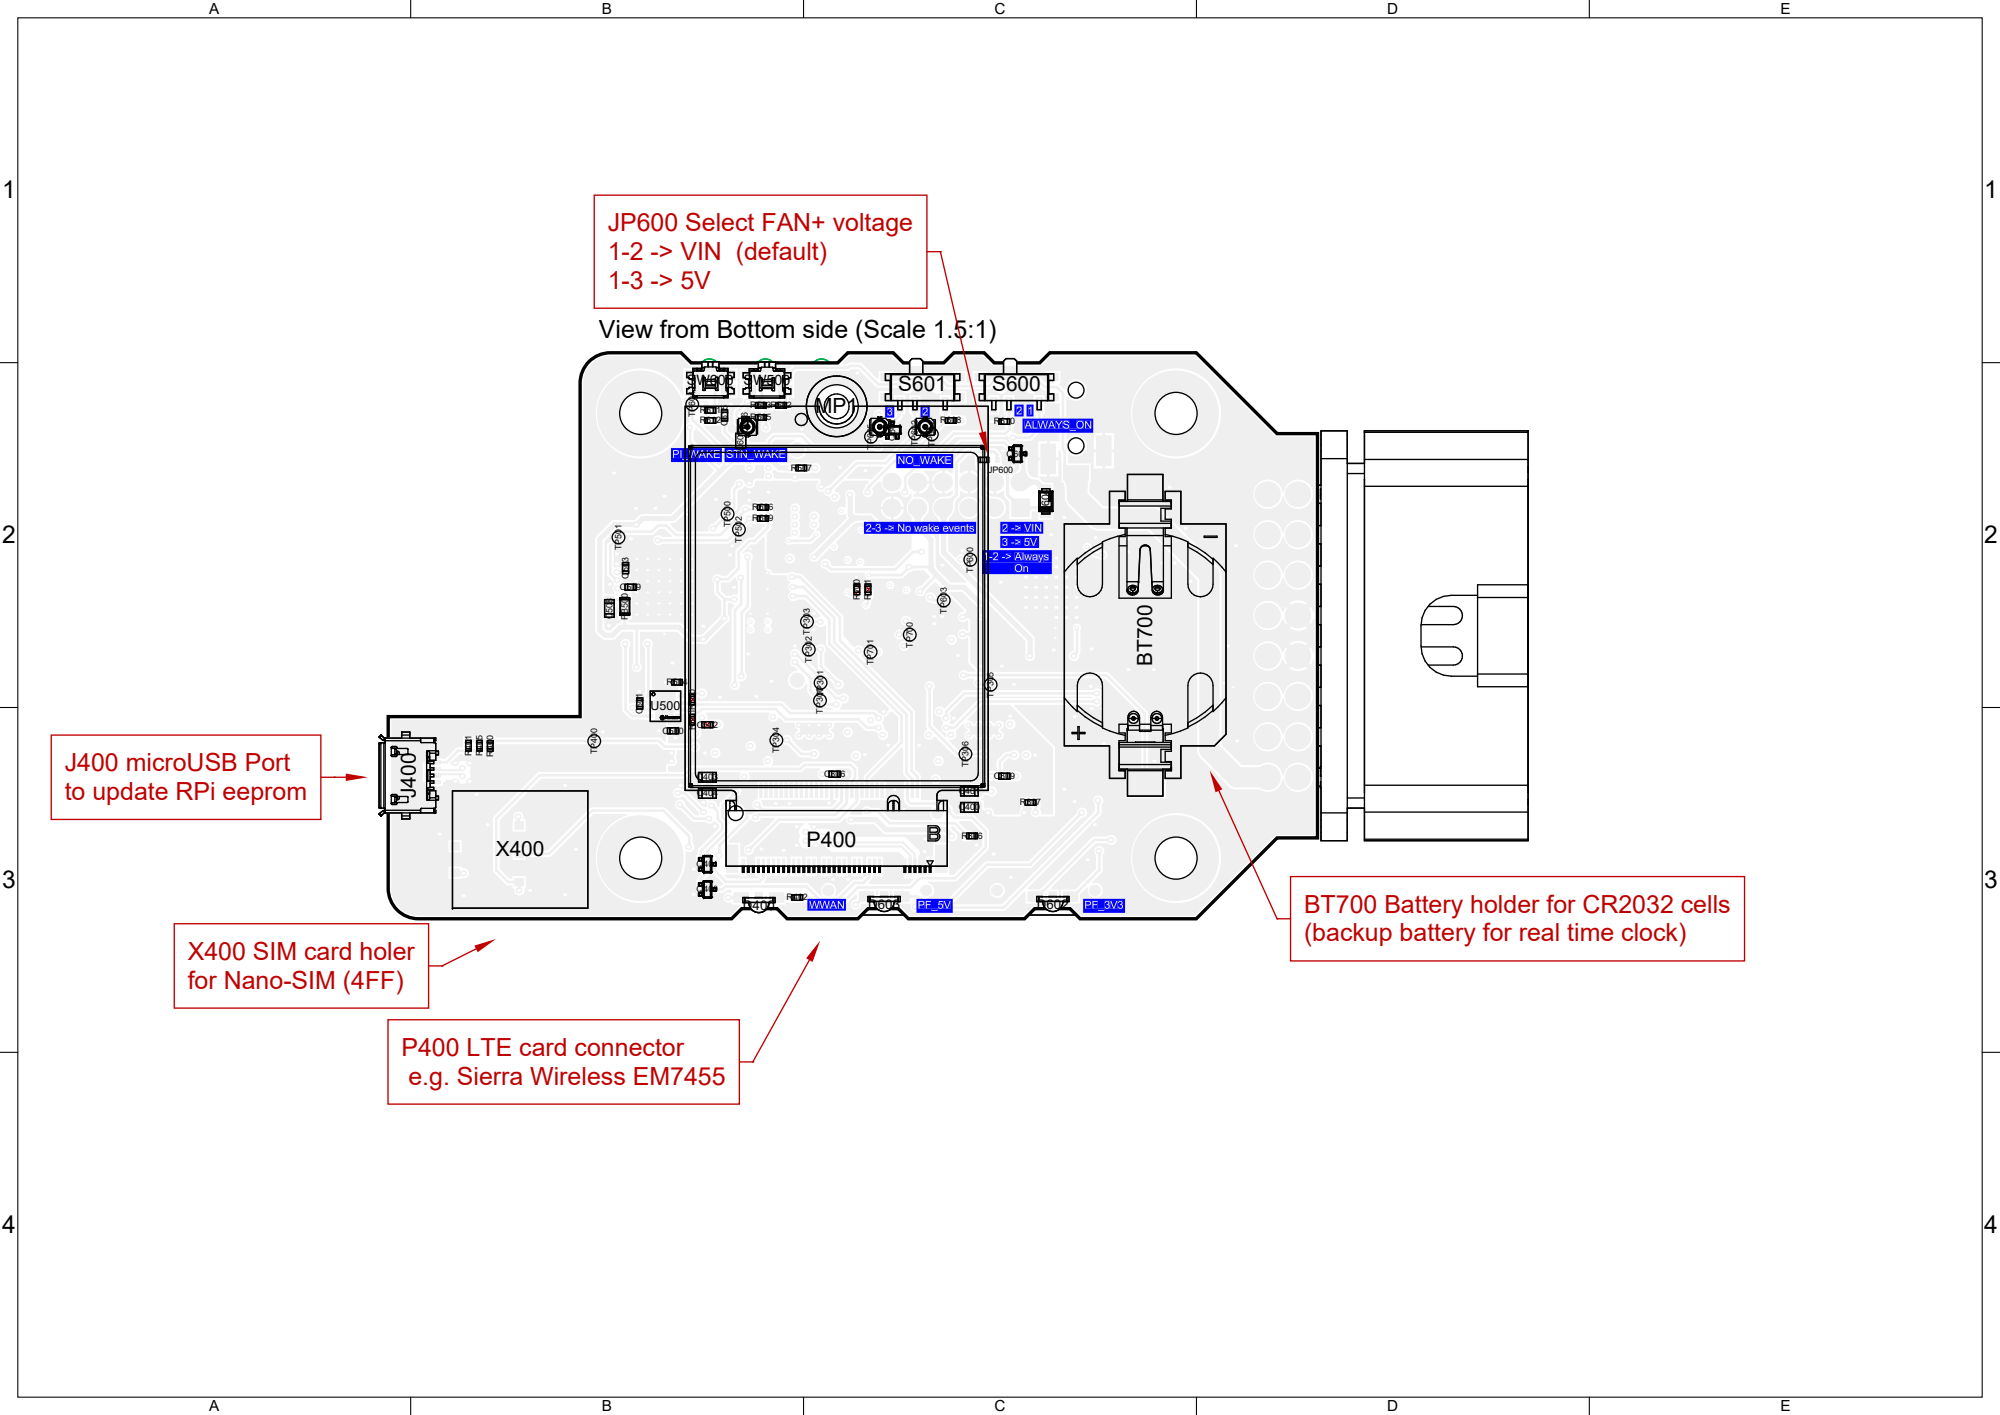
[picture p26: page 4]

JP600 Select FAN+ voltage
1-2 -> VIN (default)
View from Bottom side (Scale 1.5:1)

J400 microUSB Port
to update RPi eeprom

BT700 Battery holder for CR2032 cells
(backup battery for real time clock)

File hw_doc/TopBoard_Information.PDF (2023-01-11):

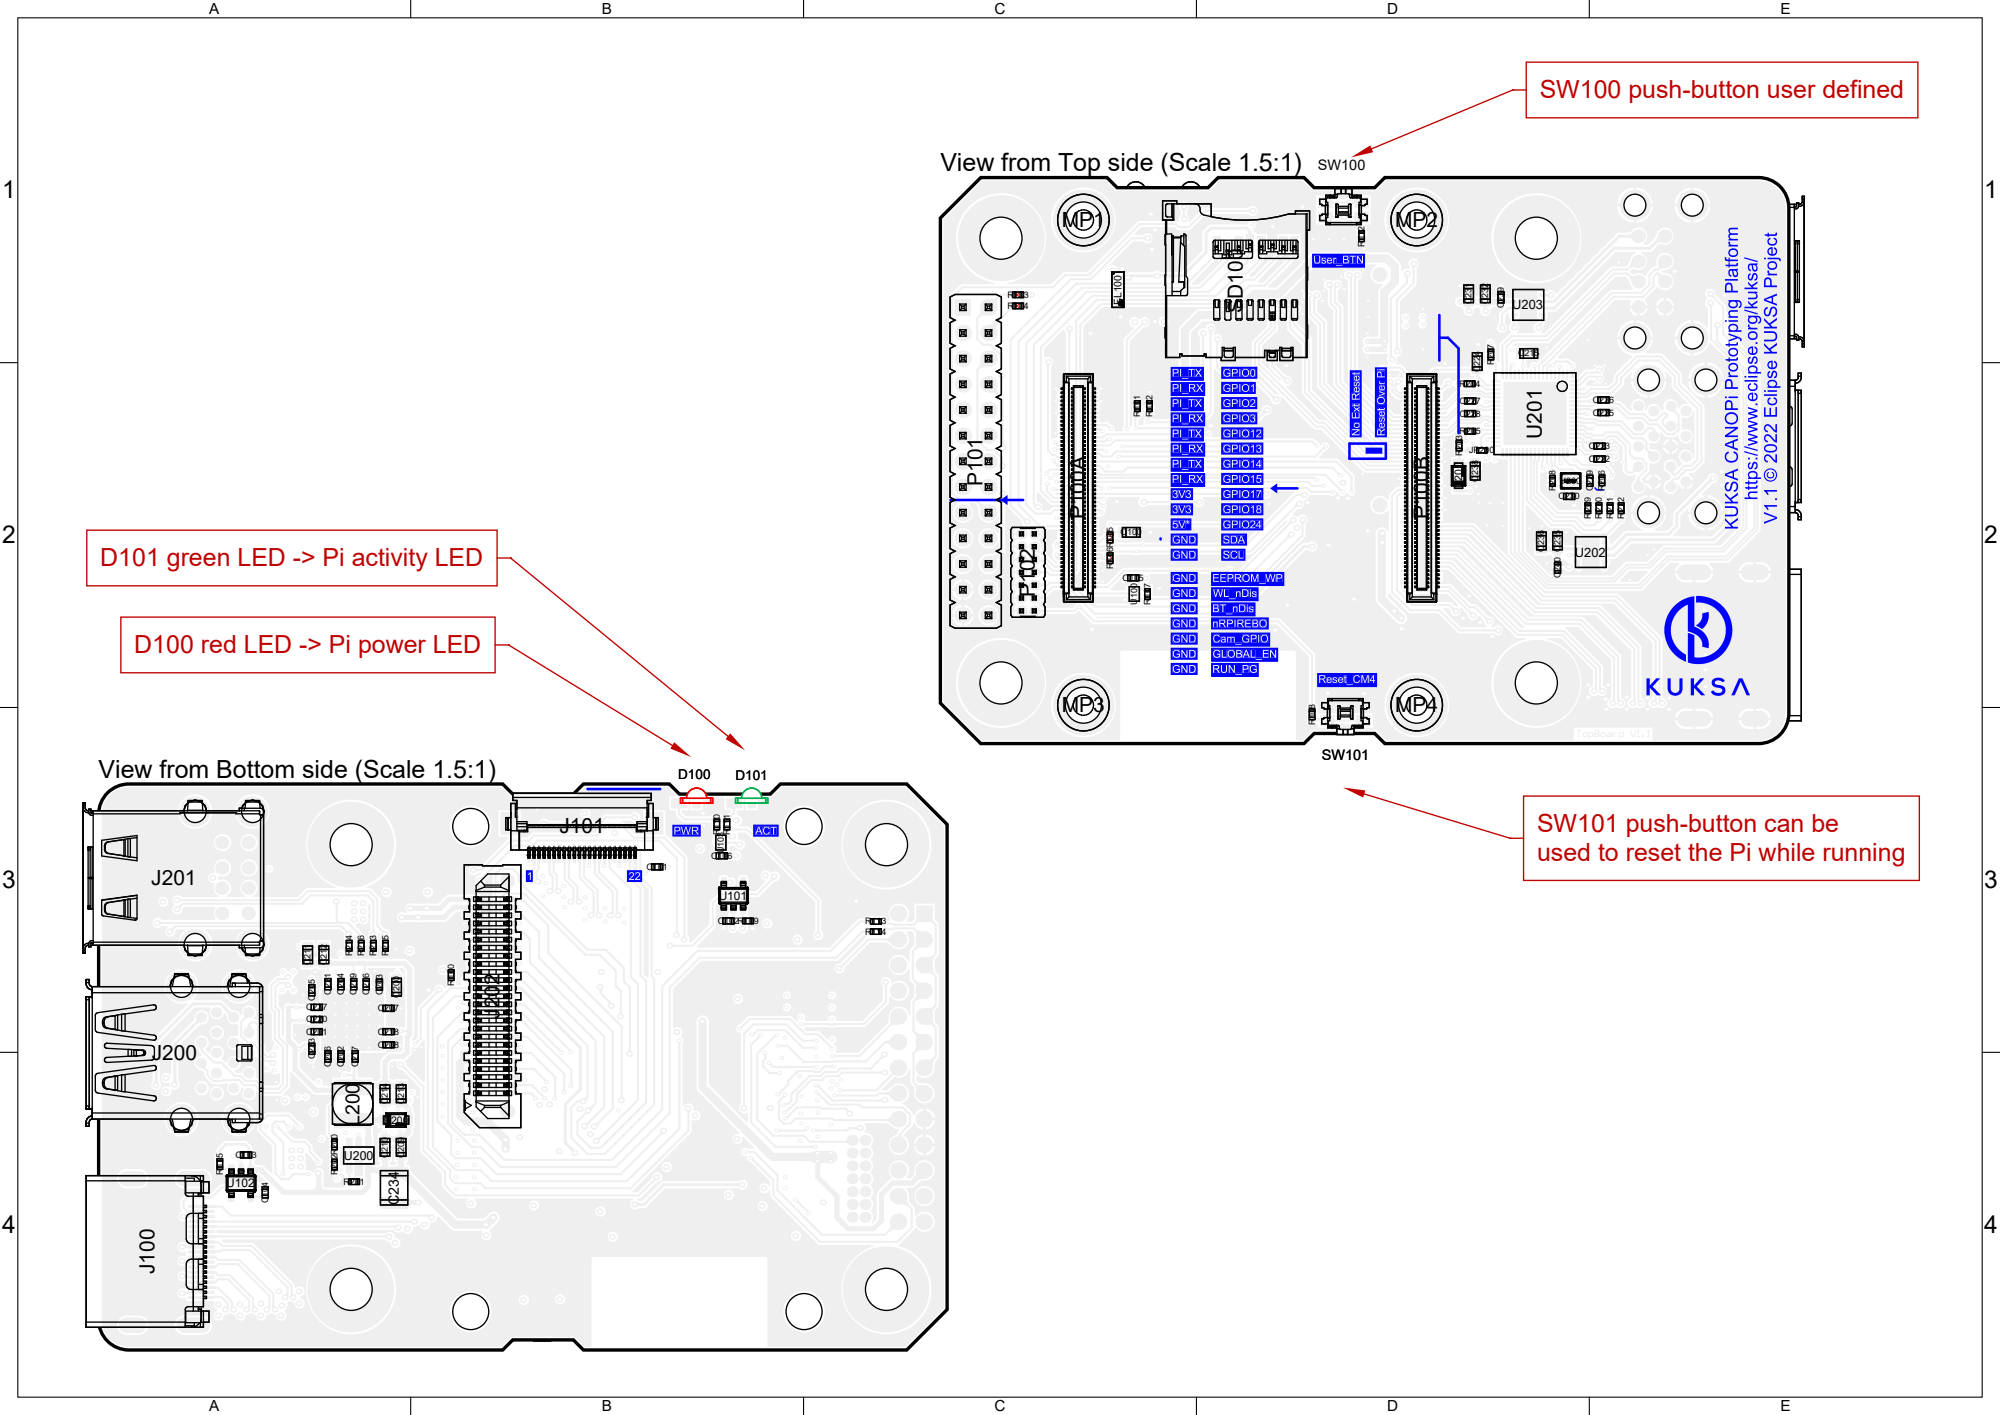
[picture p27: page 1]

SW100 push-button user defined

View from Top side (Scale 1.5:1)

D101 green LED -> Pi activity LED

D100 red LED -> Pi power LED

View from Bottom side (Scale 1.5:1)

SW101 push-button can be
used to reset the Pi while running


set jumper to connect Pi with STN2120 chip
(default jumper PI_TX-GPIO14 and PI_RX-GPIO15)
DETAIL C (Scale 2.3:1) P102

SD100 SD-Card slot for CM4 Lite modules

View from Top side (Scale 1.5:1)

JP200 Triple jumper
-> Reset signal to USB-Hub from Pi
(default, 0R between1-2)

https://datasheets.raspberrypi.com/cm4/cm4-datasheet.pdf


View from Bottom side (Scale 1.5:1)

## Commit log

2019-10-01 Feature/kuksa hw (#95)
    * Schematics, Layout and Manufacturing files for KUKSA Retrofit Prototyping Platform
    [1fach_Nutzen.GBL, 1fach_Nutzen.GBO, 1fach_Nutzen.GBP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]
2019-12-16 Manufacturing files for PiOBD housing
    [antenna-bracket-basic.stl, antenna-bracket-lock.stl, housing-bottom.stl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]
2021-07-13 Update housing top part and documentation
    The new version contains holes for HDMI and OTG-USB connection, enabling
    easier debugging without needing to remove the hardware from the
    housing
    [housing-top.stl]
2021-07-19 Add README for housing, mention Adobe reader requirement
2022-04-05 Feature/hardware v2 (#5)
    * Move V1 documentation
    * Add schematic and board PDFs
    * Add Gerbers
    * Initial Readme Content
    * EEPROM flashing instructions
    * Add picture for jumper
    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
    [1fach_Nutzen.GBL, 1fach_Nutzen.GBO, 1fach_Nutzen.GBP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]
2023-01-11 More info in Documentation, BOM xls and Pick and Place Files
    [BaseBoard.PrjPcb, BaseBoard_Panel.PcbDoc, Bill of Materials, Layer-BaseBoard(BASIC).xls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]
